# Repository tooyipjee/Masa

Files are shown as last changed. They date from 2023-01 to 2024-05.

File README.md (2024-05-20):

**Masa: A Smart, Energy-Efficient Retro Clock**
=====================================================
**Introduction**
---------------
Masa, the Malaysian word for time, is a project that brings together modern electronic components to achieve a beautiful vintage look. Masa combines the aesthetic of traditional Nixie tubes with modern LED technology and advanced features.

**Project Overview**
--------------------
Masa is a type of electronic clock that replicates the vintage aesthetic of traditional Nixie clocks while using modern LED technology. It displays the time and can also display additional panels such as weather, tickers, and other illustrations. Masa has internet connectivity, allowing it to retrieve data from the internet and features several onboard environmental sensors.

**Key Features**
----------------
* LEDs with full brightness and color control
* Environmental sensor to measure room temperature and humidity
* Phototransistor for ambient light measurement
* ESP32-S2 to drive and interface with sensors and get the latest time from the NTP server over WiFi
* Compatible with rapidly prototype-able Cricut-based perspex "displays"
* Powered by USB-C

**Specification**
---------------
* Microcontroller: ESP32-S2
* WiFi: 802.11b/g/n
* FLASH: 4MB
* Programming: USB over UART
* Humidity and Temperature Sensor: SHT20
    + Capacitive type humidity sensor
    + Band gap temperature sensor
    + Digital processing unit - I2C
* Light Sensor: TEMT6000X01
    + High photo sensitivity
    + Adapted to human eye responsivity
    + Angle of half sensitivity ± 60°
* Power: USB-C + 3.3V LDO

**Acknowledgement**
----------------
Special thanks to JLCPCB for sponsoring this project. Their rapid prototyping and high-quality assembly services enabled us to bring this project to life.

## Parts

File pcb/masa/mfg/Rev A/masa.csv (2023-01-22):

Comment | Designator | Footprint | LCSC
ANT3216LL00R2400A | AE1 | Resistor_SMD:R_1206_3216Metric_Pad1.30x1.75mm_HandSolder | C293767
10u | C3,C44,C45,C117,C121,C122 | Capacitor_SMD:C_0805_2012Metric | C15850
100uF_E | C118,C119,C120 | Capacitor_SMD:CP_Elec_6.3x7.7 | C127971
100p | C14 | Capacitor_SMD:C_0402_1005Metric | C1546
100n | C1,C2,C10,C13,C15,C16,C17,C18,C21,C22,C23,C24,C25,C26,C27,C28,C29,C30,C31,C32,C33,C34,C35,C36,C37,C38,C39,C40,C41,C42,C43,C46,C47,C48,C49,C50,C51,C52,C53,C54,C55,C56,C57,C58,C59,C60,C61,C62,C63,C64,C65,C66,C67,C68,C69,C70,C71,C72,C73,C74,C75,C76,C77,C78,C79,C80,C81,C82,C83,C84,C85,C86,C87,C88,C89,C90,C91,C92,C93,C94,C95,C96,C97,C98,C99,C100,C101,C102,C103,C104,C105,C106,C107,C108,C109,C110,C111,C112,C113,C114,C115,C116,C124,C125 | Capacitor_SMD:C_0402_1005Metric | C307331
1u | C4,C12,C19,C20 | Capacitor_SMD:C_0402_1005Metric | C52923
20p | C5,C9 | Capacitor_SMD:C_0402_1005Metric | C1554
4p | C6 | Capacitor_SMD:C_0402_1005Metric | C311704
10u_0402 | C7,C11 | Capacitor_SMD:C_0402_1005Metric | C315248
5p | C8 | Capacitor_SMD:C_0402_1005Metric | C1573
Green_0603 | D1,D2,D3 | LED_SMD:LED_0603_1608Metric | C72043
MountingHole | H1,H2,H3,H4,H5,H6,H7,H8,H9,H10,H11,H12,H13,H14,H15,H16,H17,H18,H19,H20,H21,H22,H23,H24 | MountingHole:MountingHole_2.7mm_M2.5
ESP32-S2FH4 | IC1 | QFN40P700X700X90-57N-D | C2840995
AMS1117-3.3 | IC2 | Package_TO_SOT_SMD:SOT-223-3_TabPin2 | C6186
W25Q64JVSSIQ | IC3 | SOIC127P790X216-8N | C83140
SHT20 | IC4 | SON100P300X300X110-7N
TXS0108EPWR | IC5 | SOP65P640X120-20N | C17206
U.FL-R-SMT-1_10_ | J1 | SamacSys_Parts:U.FL-R-SMT-1_10_ | C88373
GT-USB-7010 | J2 | Connectors_JT:GT-USB-7010A | C963370
TC2050-IDC | J3 | TC2050-IDC
KF350-3.5-2P | J4 | KF350352P | C474892
1.8nH | L1,L2 | Inductor_SMD:L_0402_1005Metric
WS2812B-2020 | LED1,LED2,LED3,LED4,LED5,LED6,LED7,LED8,LED9,LED10,LED11,LED12,LED13,LED14,LED15,LED16,LED17,LED18,LED19,LED20,LED21,LED22,LED23,LED24,LED25,LED26,LED27,LED28,LED29,LED30,LED31,LED32,LED33,LED34,LED35,LED36,LED37,LED38,LED39,LED40,LED41,LED42,LED43,LED44,LED45,LED46,LED47,LED48,LED49,LED50,LED51,LED52,LED53,LED54,LED55,LED56,LED57,LED58,LED59,LED60,LED61,LED62,LED63,LED64,LED65,LED66,LED67,LED68,LED69,LED70,LED71,LED72,LED73,LED74,LED75,LED76,LED77,LED78,LED79,LED80,LED81,LED82,LED83,LED84,LED85,LED86,LED87,LED88,LED89,LED90,LED91,LED92,LED93 | WS2812B2020 | C965555
MUN5214DW1T1G | Q1 | Package_TO_SOT_SMD:SOT-363_SC-70-6 | C94403
TEMT6000X01 | Q2 | TEMT6000X01 | C94098
DNF_0402 | R1 | Resistor_SMD:R_0402_1005Metric
4.7k | R11,R12 | Resistor_SMD:R_0402_1005Metric | C25900
2.2k | R16 | Resistor_SMD:R_0402_1005Metric | C25879
1k | R2,R3 | Resistor_SMD:R_0402_1005Metric | C11702
DNF_0805 | R4,R9,R13 | Resistor_SMD:R_0805_2012Metric_Pad1.20x1.40mm_HandSolder
0 | R5,R14,R15 | Resistor_SMD:R_0805_2012Metric_Pad1.20x1.40mm_HandSolder | C17477
10k | R6,R7,R8,R10,R17 | Resistor_SMD:R_0402_1005Metric | C25744
TS-1101-C-W | S1,S2 | TS1101CW | C318938
K3-1296S-E1 | S3 | K31296SE1 | C128955
TestPoint | TP1,TP2,TP3,TP5,TP9,TP10,TP11,TP12 | TestPoint:TestPoint_THTPad_D1.0mm_Drill0.5mm
TestPoint | TP4,TP6,TP7,TP8 | TestPoint:TestPoint_THTPad_1.0x1.0mm_Drill0.5mm
CH340C | U1 | Package_SO:SOIC-16_3.9x9.9mm_P1.27mm | C84681
SX25Y040000BF1T-C | Y1 | Crystal:Crystal_SMD_2520-4Pin_2.5x2.0mm | C271649

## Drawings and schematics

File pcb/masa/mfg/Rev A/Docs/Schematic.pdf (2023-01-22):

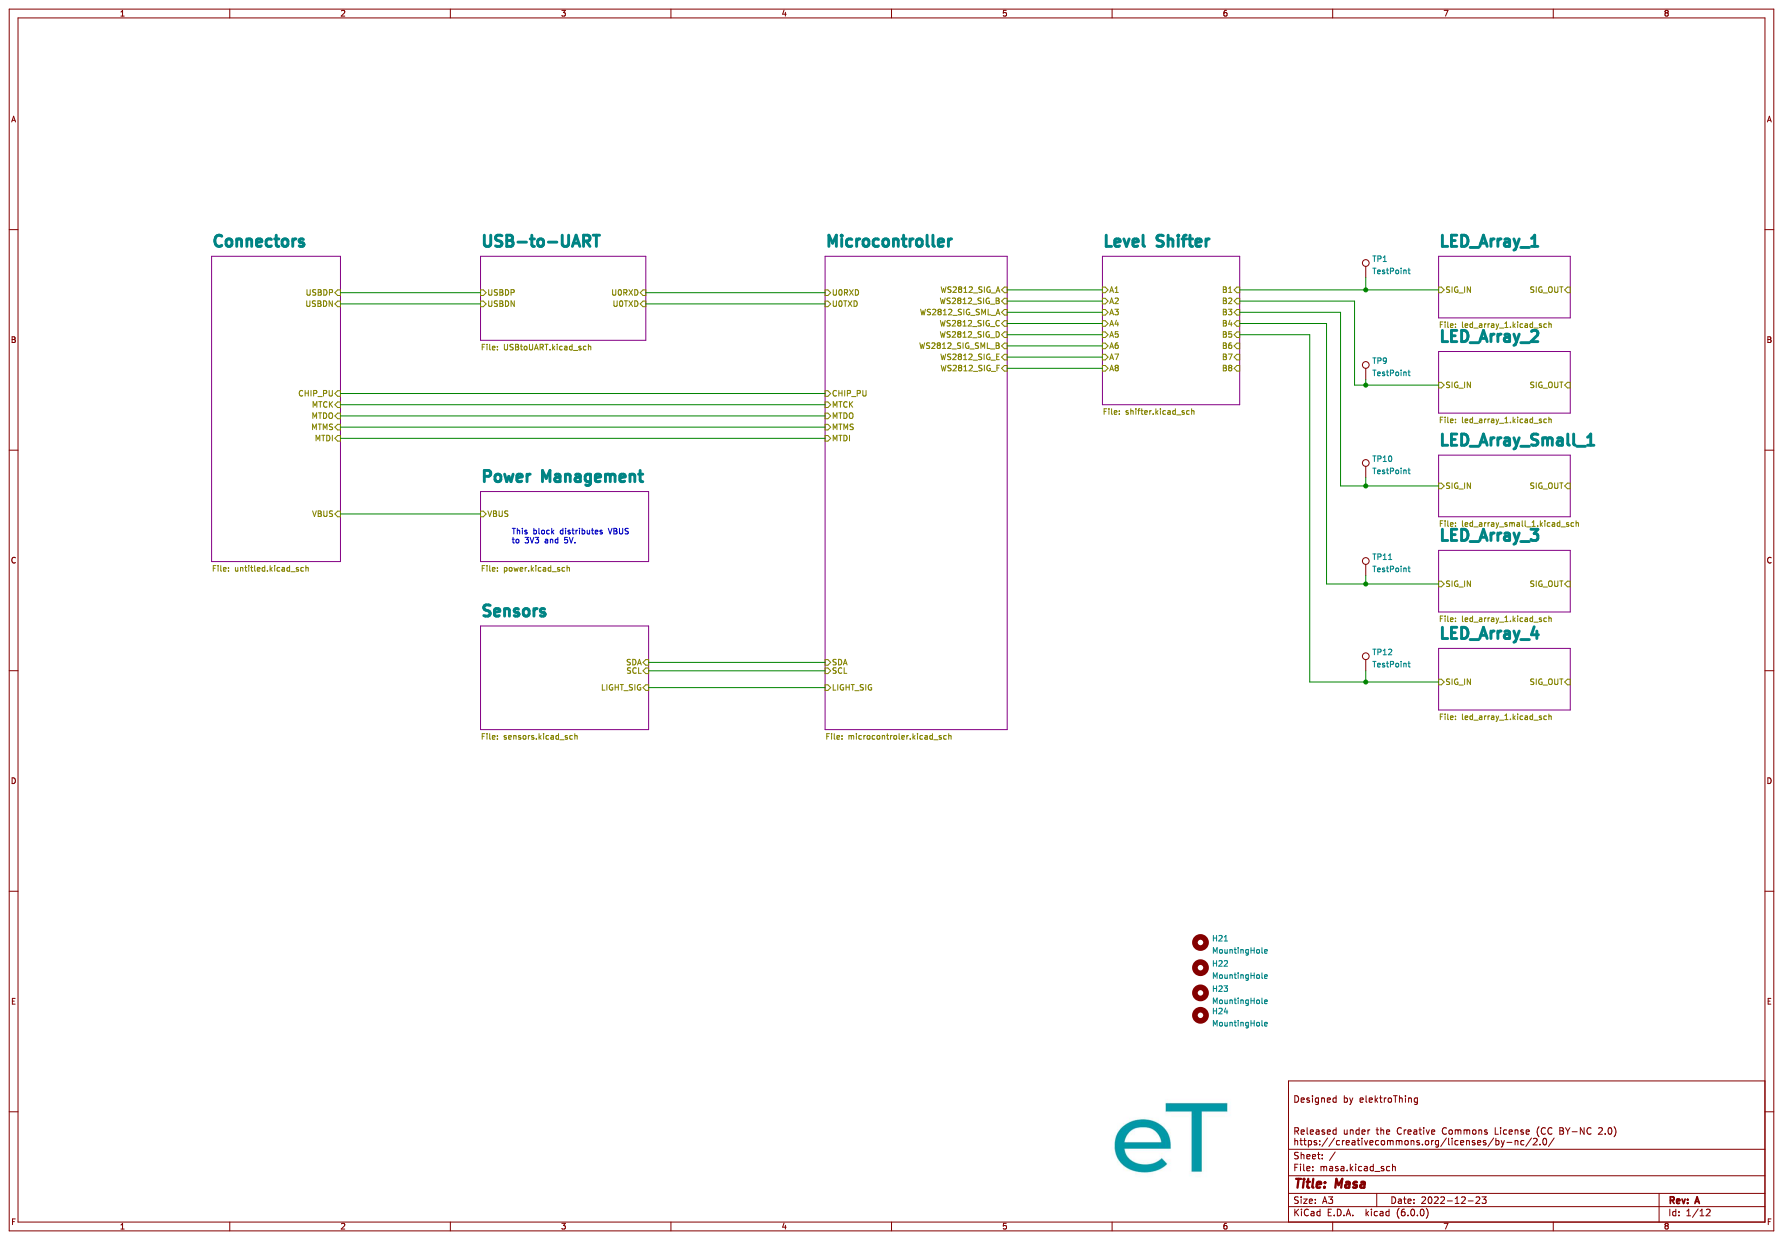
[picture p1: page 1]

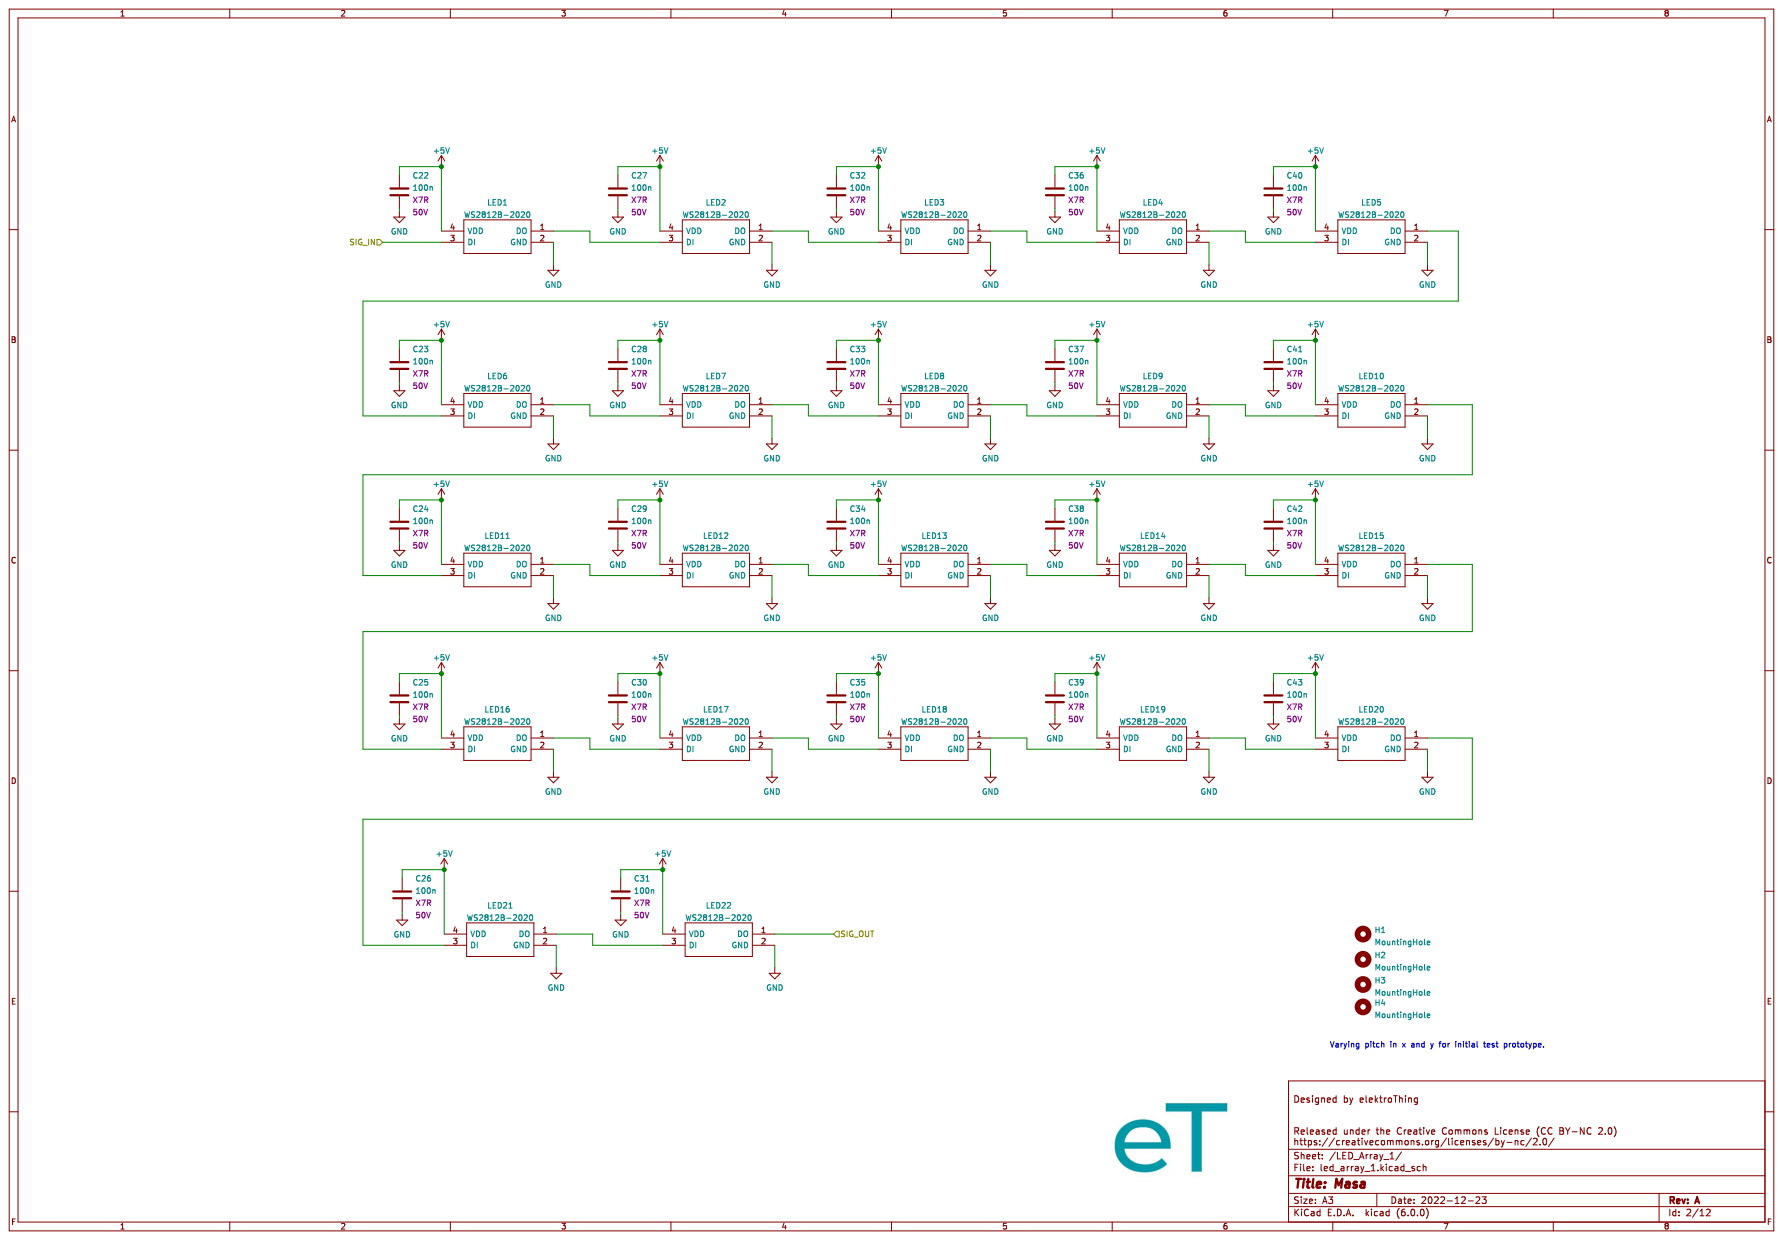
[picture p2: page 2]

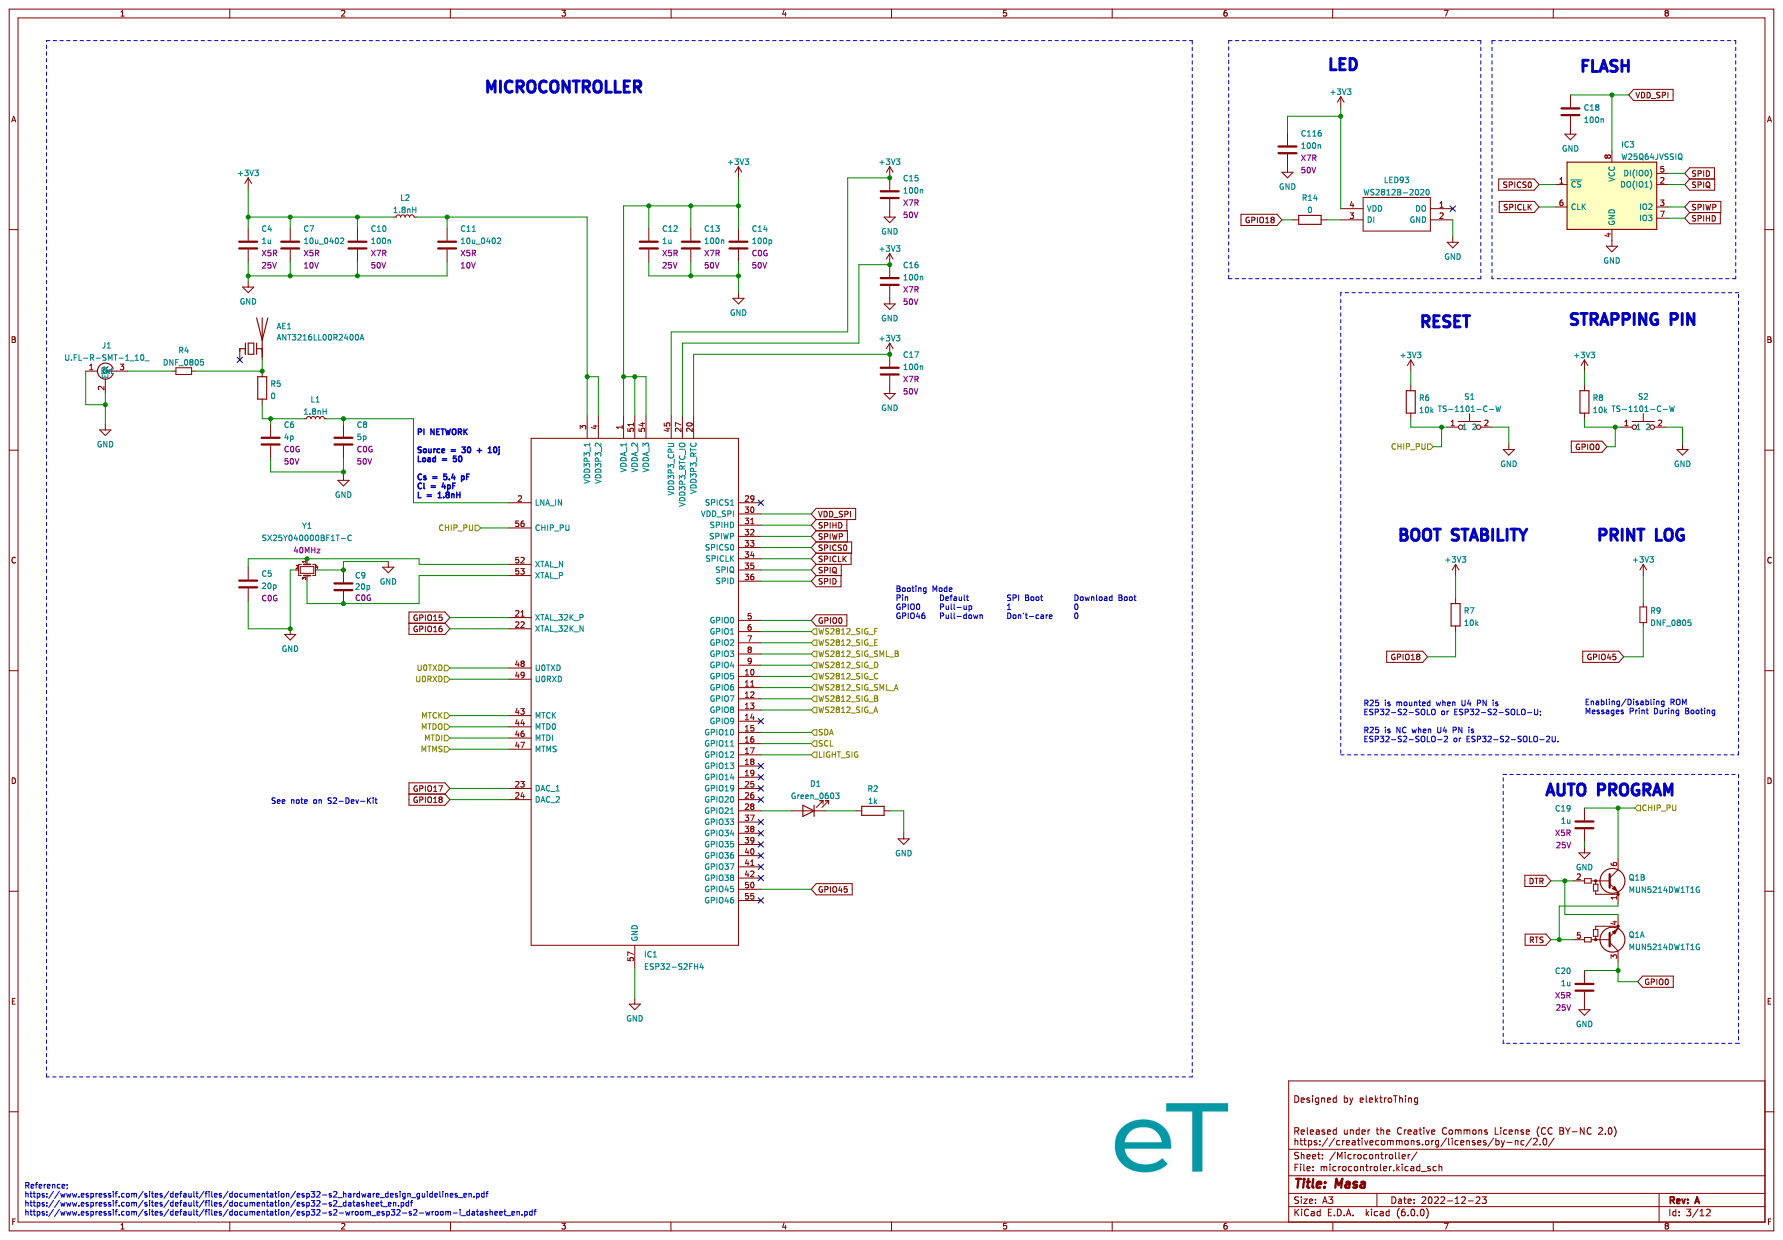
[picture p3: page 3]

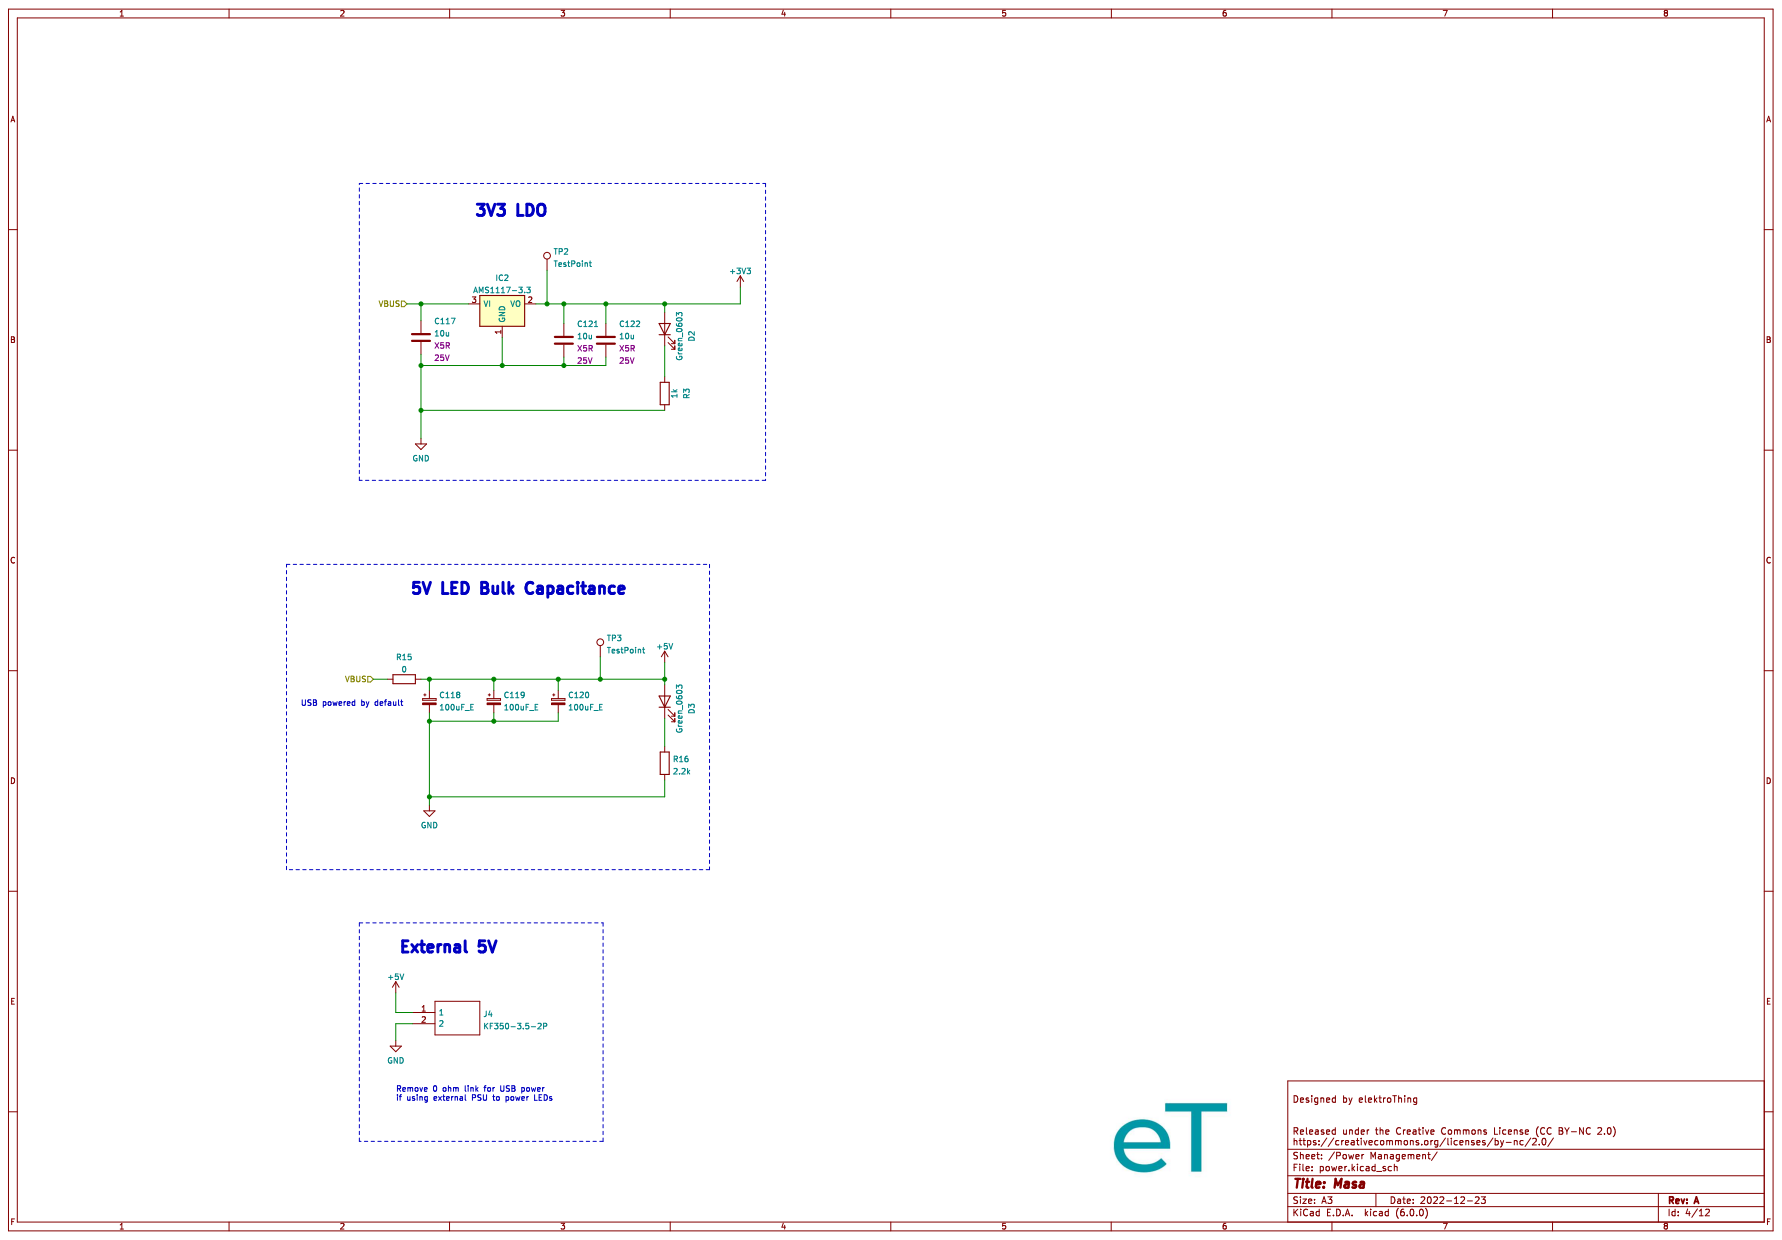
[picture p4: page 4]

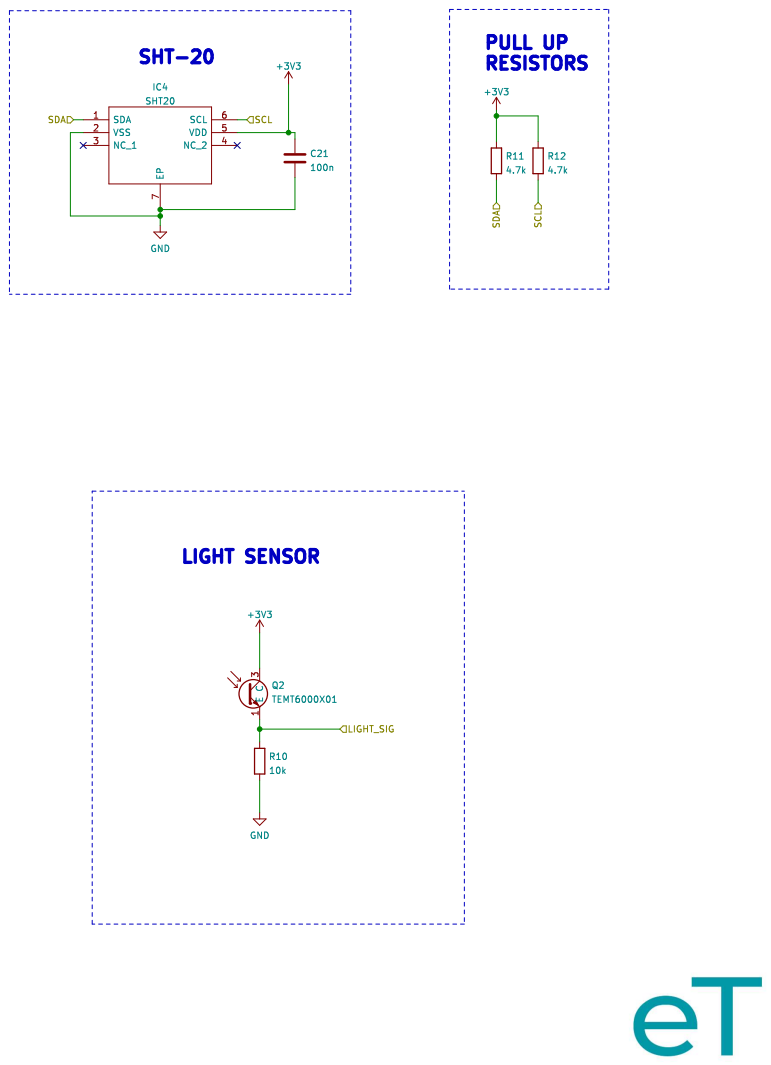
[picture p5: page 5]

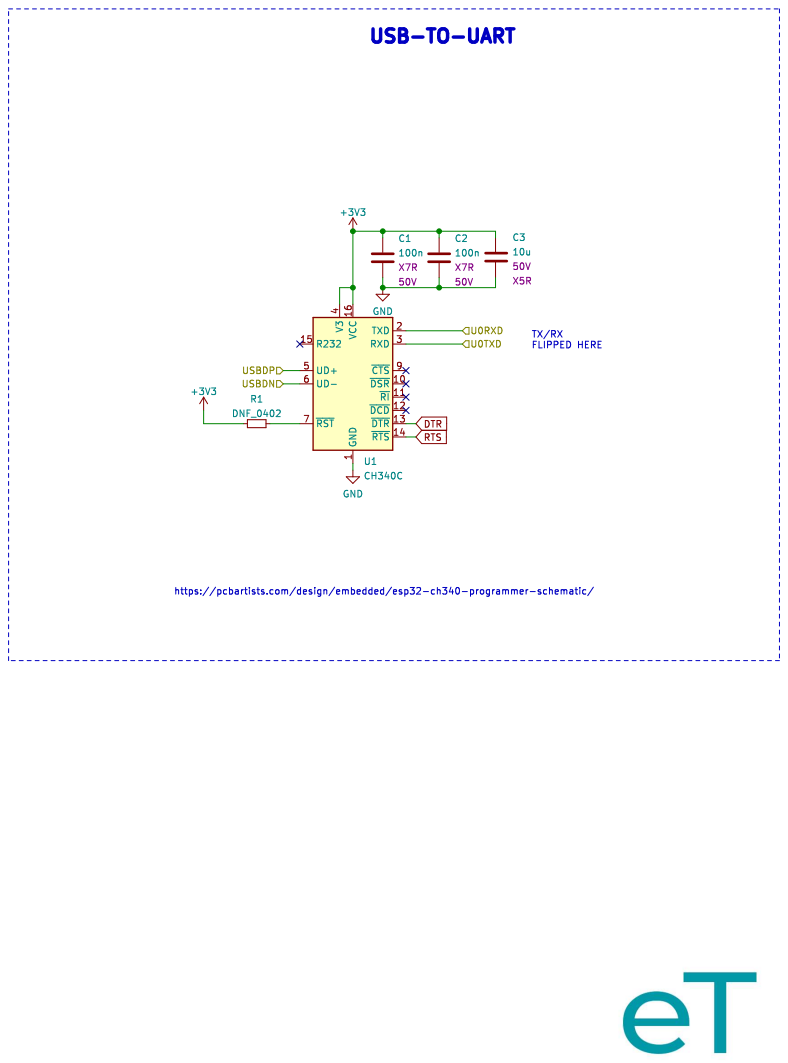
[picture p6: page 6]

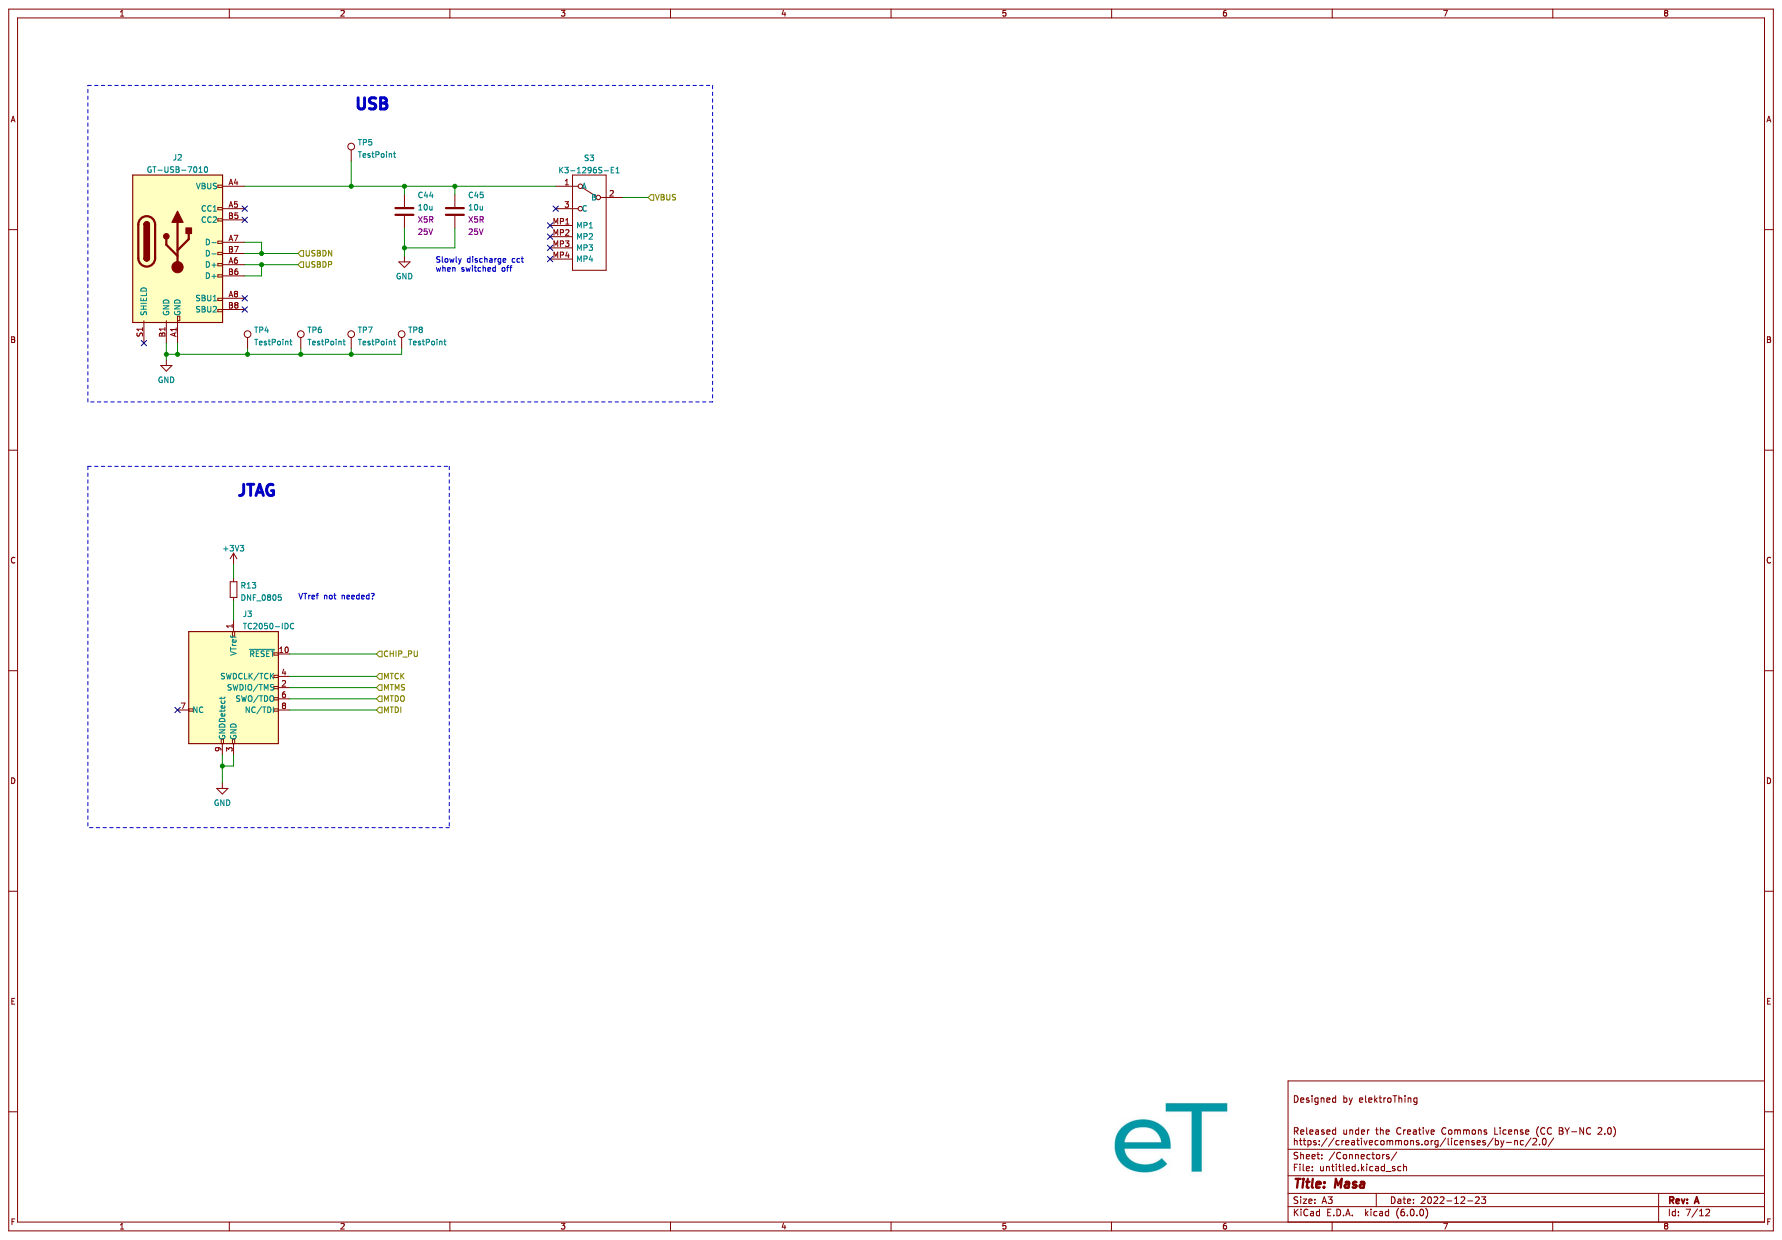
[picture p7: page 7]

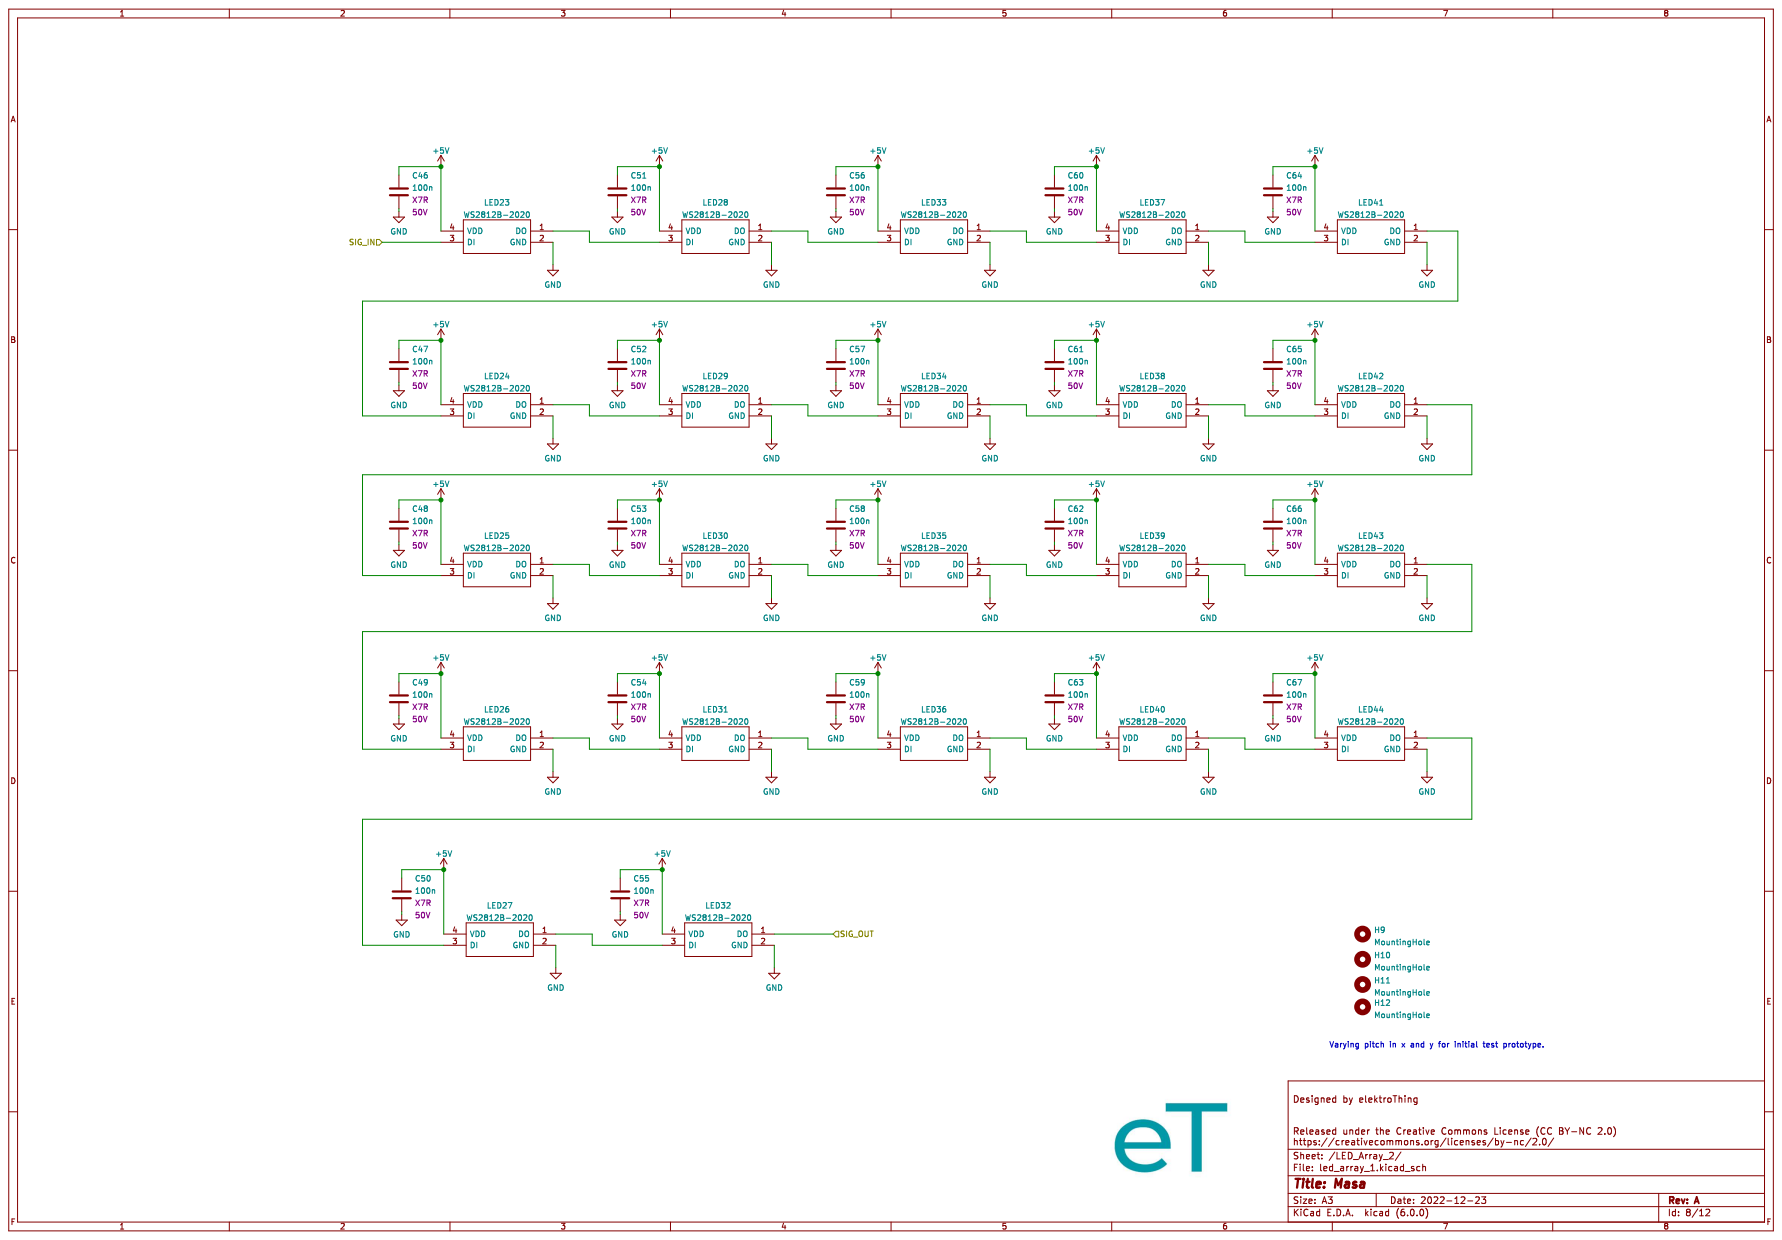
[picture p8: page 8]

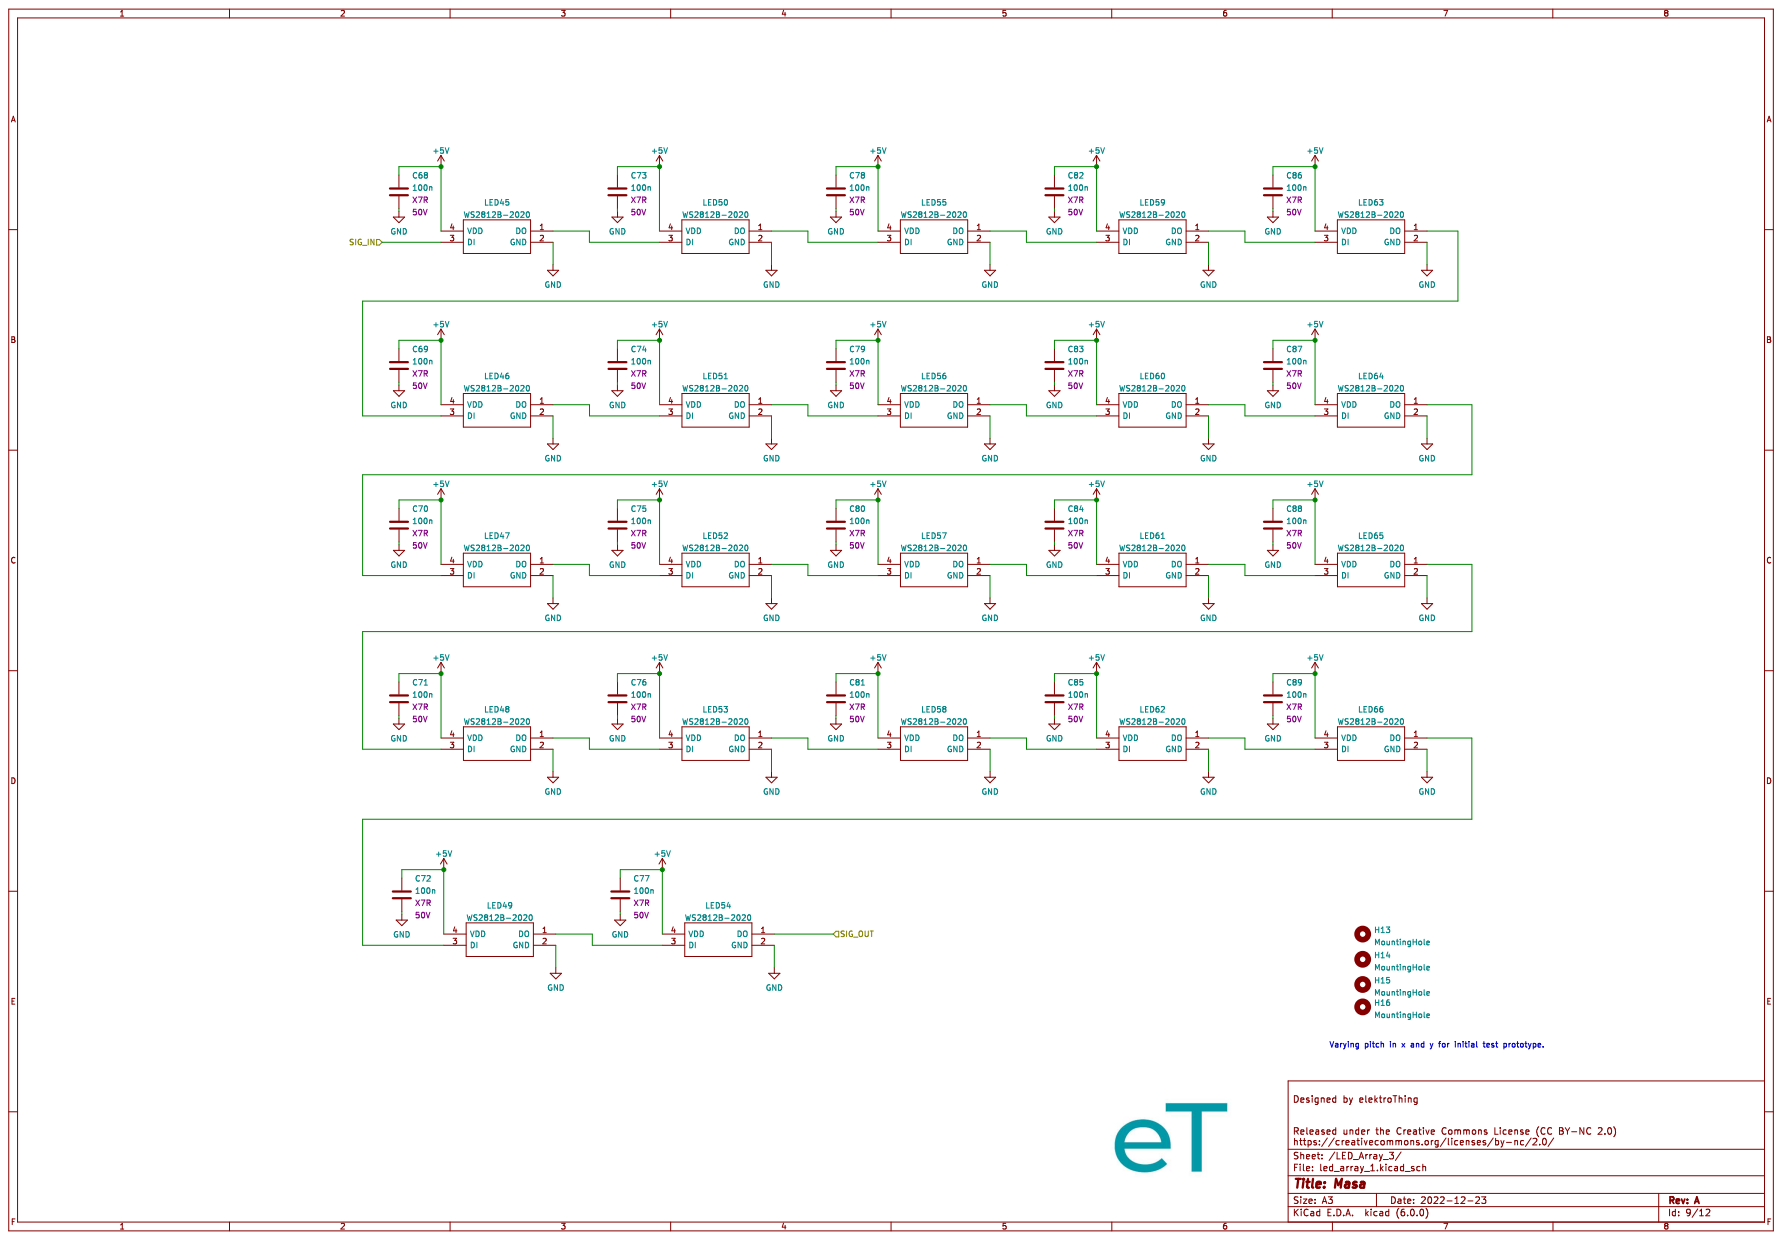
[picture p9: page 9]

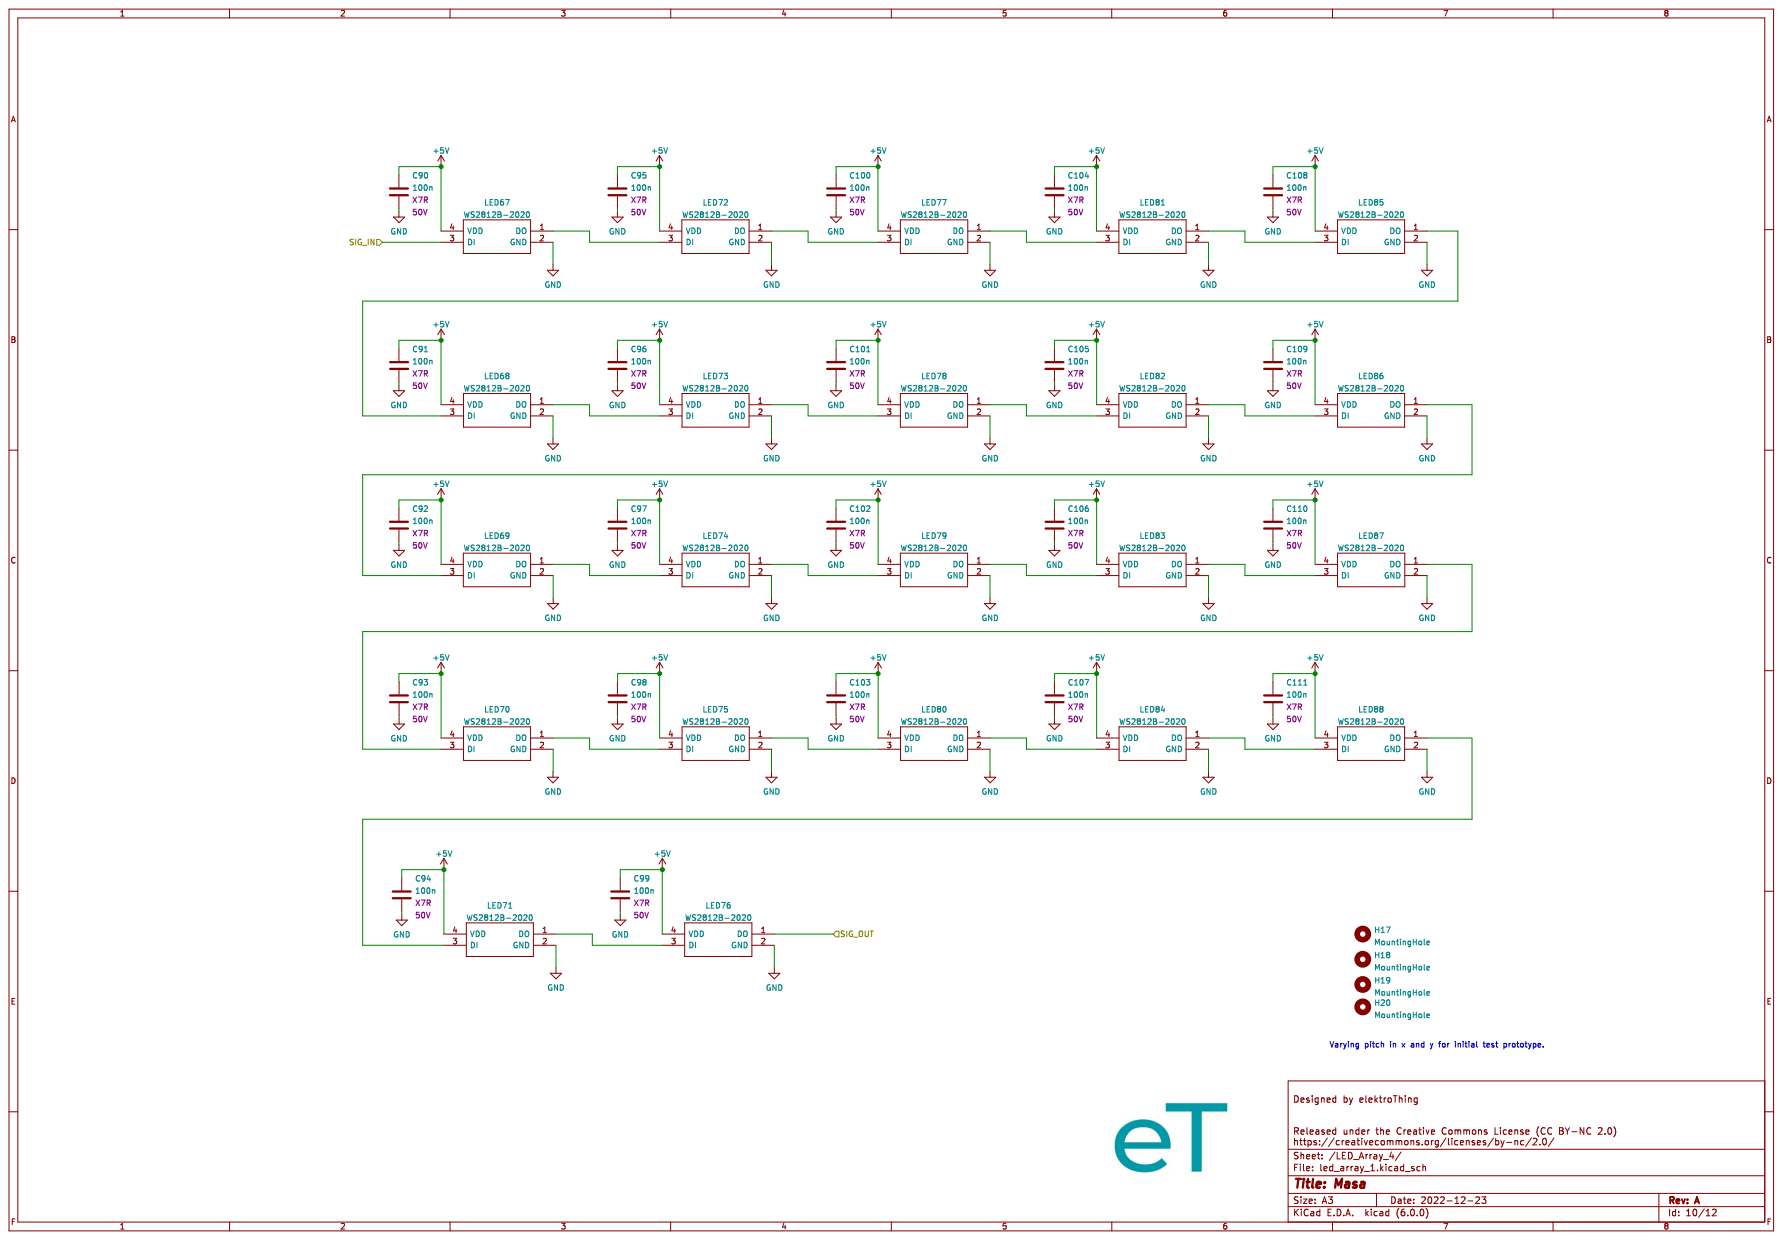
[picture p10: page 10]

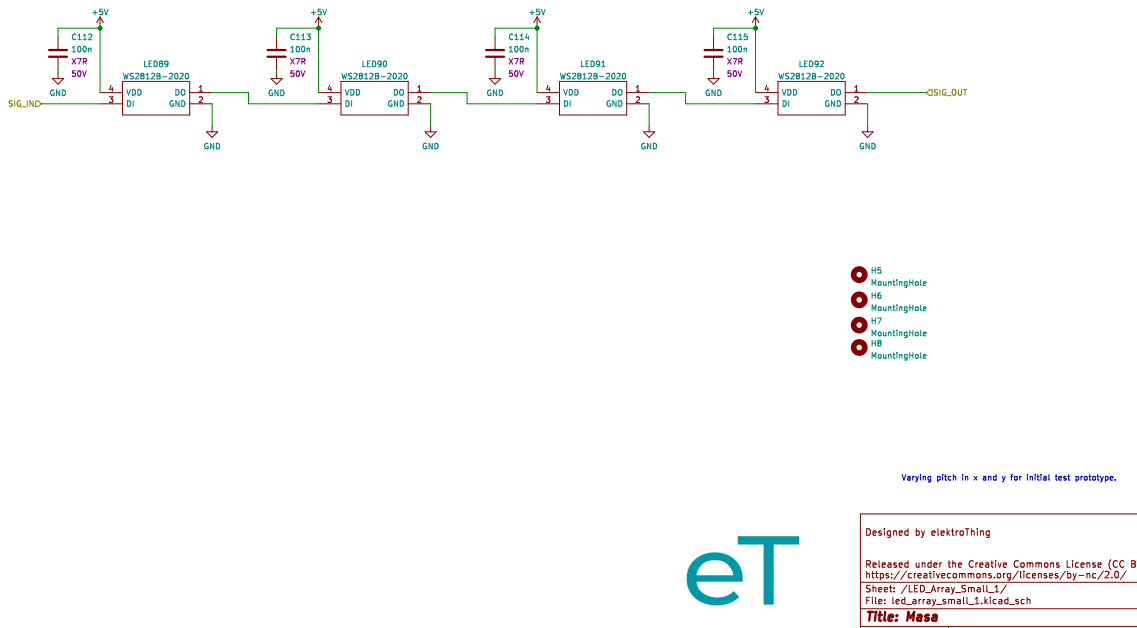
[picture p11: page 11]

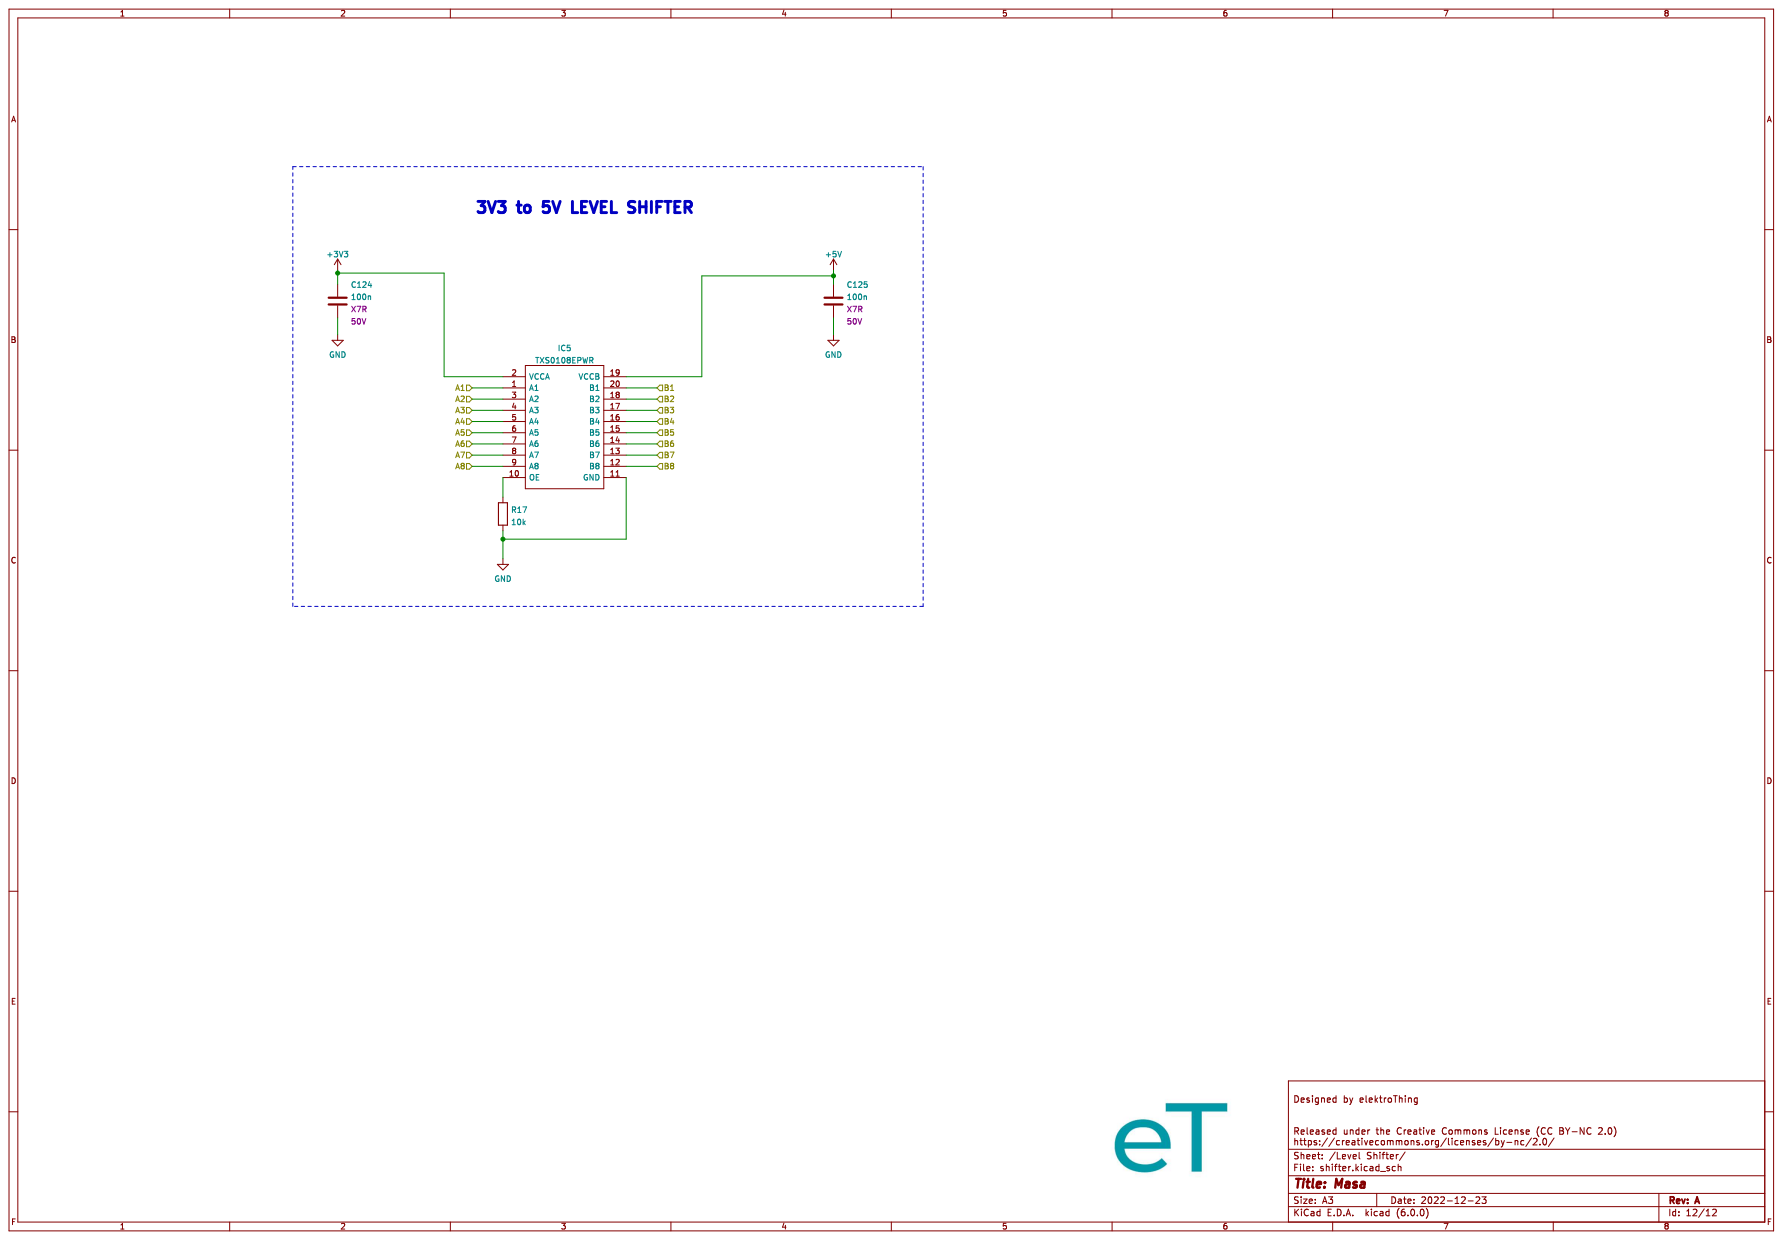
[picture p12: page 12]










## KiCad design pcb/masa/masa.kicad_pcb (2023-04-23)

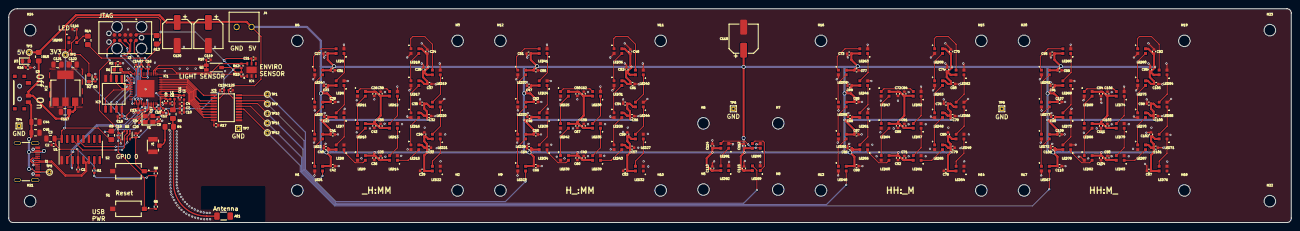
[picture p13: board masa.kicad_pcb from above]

Board: 4 copper layers, 300.0 x 50.0 mm, 292 parts (0 on the bottom side), 144 nets.

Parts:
AE1: ANT3216LL00R2400A; R_1206_3216Metric_Pad1.30x1.75mm_HandSolder
C1, C2, C10, C13, C15, C16, C17, C18, C21, C22, C23, C24, C25, C26, C27, C28, C29, C30, C31, C32, C33, C34, C35, C36, C37, C38, C39, C40, C41, C42, C43, C46, C47, C48, C49, C50, C51, C52, C53, C54, C55, C56, C57, C58, C59, C60, C61, C62, C63, C64, C65, C66, C67, C68, C69, C70, C71, C72, C73, C74, C75, C76, C77, C78, C79, C80, C81, C82, C83, C84, C85, C86, C87, C88, C89, C90, C91, C92, C93, C94, C95, C96, C97, C98, C99, C100, C101, C102, C103, C104, C105, C106, C107, C108, C109, C110, C111, C112, C113, C114, C115, C116, C124, C125: 100n; C_0402_1005Metric
C3, C44, C45, C117, C121, C122: 10u; C_0805_2012Metric
C4, C12, C19, C20: 1u; C_0402_1005Metric
C5, C9: 20p; C_0402_1005Metric
C6: 4p; C_0402_1005Metric
C7, C11: 10u_0402; C_0402_1005Metric
C8: 5p; C_0402_1005Metric
C14: 100p; C_0402_1005Metric
C118, C119, C120: 100uF_E; CP_Elec_6.3x7.7
D1, D2, D3: Green_0603; LED_0603_1608Metric
H1, H2, H3, H4, H5, H6, H7, H8, H9, H10, H11, H12, H13, H14, H15, H16, H17, H18, H19, H20, H21, H22, H23, H24: MountingHole; MountingHole_2.7mm_M2.5
IC1: ESP32-S2FH4; QFN40P700X700X90-57N-D
IC2: AMS1117-3.3; SOT-223-3_TabPin2
IC3: W25Q64JVSSIQ; SOIC127P790X216-8N
IC4: SHT20; SON100P300X300X110-7N
IC5: TXS0108EPWR; SOP65P640X120-20N
J1: U.FL-R-SMT-1_10_
J2: GT-USB-7010; GT-USB-7010A
J3: TC2050-IDC
J4: KF350-3.5-2P; KF350352P
L1, L2: 1.8nH; L_0402_1005Metric
LED1, LED2, LED3, LED4, LED5, LED6, LED7, LED8, LED9, LED10, LED11, LED12, LED13, LED14, LED15, LED16, LED17, LED18, LED19, LED20, LED21, LED22, LED23, LED24, LED25, LED26, LED27, LED28, LED29, LED30, LED31, LED32, LED33, LED34, LED35, LED36, LED37, LED38, LED39, LED40, LED41, LED42, LED43, LED44, LED45, LED46, LED47, LED48, LED49, LED50, LED51, LED52, LED53, LED54, LED55, LED56, LED57, LED58, LED59, LED60, LED61, LED62, LED63, LED64, LED65, LED66, LED67, LED68, LED69, LED70, LED71, LED72, LED73, LED74, LED75, LED76, LED77, LED78, LED79, LED80, LED81, LED82, LED83, LED84, LED85, LED86, LED87, LED88, LED89, LED90, LED91, LED92, LED93: WS2812B-2020; WS2812B2020
Q1: MUN5214DW1T1G; SOT-363_SC-70-6
Q2: TEMT6000X01
R1: DNF_0402; R_0402_1005Metric
R2, R3: 1k; R_0402_1005Metric
R4, R9, R13: DNF_0805; R_0805_2012Metric_Pad1.20x1.40mm_HandSolder
R5, R14, R15: 0; R_0805_2012Metric_Pad1.20x1.40mm_HandSolder
R6, R7, R8, R10, R17: 10k; R_0402_1005Metric
R11, R12: 4.7k; R_0402_1005Metric
R16: 2.2k; R_0402_1005Metric
S1, S2: TS-1101-C-W; TS1101CW
S3: K3-1296S-E1; K31296SE1
TP1, TP2, TP3, TP5, TP9, TP10, TP11, TP12: TestPoint; TestPoint_THTPad_D1.0mm_Drill0.5mm
TP4, TP6, TP7, TP8: TestPoint; TestPoint_THTPad_1.0x1.0mm_Drill0.5mm
U1: CH340C; SOIC-16_3.9x9.9mm_P1.27mm
Y1: SX25Y040000BF1T-C; Crystal_SMD_2520-4Pin_2.5x2.0mm

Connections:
+3V3: C1.1, C2.1, C3.1, C4.1, C7.1, C10.1, C12.1, C13.1, C14.1, C15.1, C16.1, C17.1, C21.1, C116.1, C121.1, C122.1, C124.1, D2.2 (A), IC1.1 (VDDA_1), IC1.20 (VDD3P3_RTC), IC1.27 (VDD3P3_RTC_IO), IC1.45 (VDD3P3_CPU), IC1.51 (VDDA_2), IC1.54 (VDDA_3), IC2.2 (VO), IC4.5 (VDD), IC5.2 (VCCA), L2.1, LED93.4 (VDD), Q2.3 (C), R1.2, R6.1, R7.1, R8.1, R9.1, R11.1, R12.1, R13.2, TP2.1, U1.4 (V3), U1.16 (VCC)
+5V: C22.1, C23.1, C24.1, C25.1, C26.1, C27.1, C28.1, C29.1, C30.1, C31.1, C32.1, C33.1, C34.1, C35.1, C36.1, C37.1, C38.1, C39.1, C40.1, C41.1, C42.1, C43.1, C46.1, C47.1, C48.1, C49.1, C50.1, C51.1, C52.1, C53.1, C54.1, C55.1, C56.1, C57.1, C58.1, C59.1, C60.1, C61.1, C62.1, C63.1, C64.1, C65.1, C66.1, C67.1, C68.1, C69.1, C70.1, C71.1, C72.1, C73.1, C74.1, C75.1, C76.1, C77.1, C78.1, C79.1, C80.1, C81.1, C82.1, C83.1, C84.1, C85.1, C86.1, C87.1, C88.1, C89.1, C90.1, C91.1, C92.1, C93.1, C94.1, C95.1, C96.1, C97.1, C98.1, C99.1, C100.1, C101.1, C102.1, C103.1, C104.1, C105.1, C106.1, C107.1, C108.1, C109.1, C110.1, C111.1, C112.1, C113.1, C114.1, C115.1, C118.1, C119.1, C120.1, C125.1, D3.2 (A), IC5.19 (VCCB), J4.1, LED1.4 (VDD), LED2.4 (VDD), LED3.4 (VDD), LED4.4 (VDD), LED5.4 (VDD), LED6.4 (VDD), LED7.4 (VDD), LED8.4 (VDD), LED9.4 (VDD), LED10.4 (VDD), LED11.4 (VDD), LED12.4 (VDD), LED13.4 (VDD), LED14.4 (VDD), LED15.4 (VDD), LED16.4 (VDD), LED17.4 (VDD), LED18.4 (VDD), LED19.4 (VDD), LED20.4 (VDD), LED21.4 (VDD), LED22.4 (VDD), LED23.4 (VDD), LED24.4 (VDD), LED25.4 (VDD), LED26.4 (VDD), LED27.4 (VDD), LED28.4 (VDD), LED29.4 (VDD), LED30.4 (VDD), LED31.4 (VDD), LED32.4 (VDD), LED33.4 (VDD), LED34.4 (VDD), LED35.4 (VDD), LED36.4 (VDD), LED37.4 (VDD), LED38.4 (VDD), LED39.4 (VDD), LED40.4 (VDD), LED41.4 (VDD), LED42.4 (VDD), LED43.4 (VDD), LED44.4 (VDD), LED45.4 (VDD), LED46.4 (VDD), LED47.4 (VDD), LED48.4 (VDD), LED49.4 (VDD), LED50.4 (VDD), LED51.4 (VDD), LED52.4 (VDD), LED53.4 (VDD), LED54.4 (VDD), LED55.4 (VDD), LED56.4 (VDD), LED57.4 (VDD), LED58.4 (VDD), LED59.4 (VDD), LED60.4 (VDD), LED61.4 (VDD), LED62.4 (VDD), LED63.4 (VDD), LED64.4 (VDD), LED65.4 (VDD), LED66.4 (VDD), LED67.4 (VDD), LED68.4 (VDD), LED69.4 (VDD), LED70.4 (VDD), LED71.4 (VDD), LED72.4 (VDD), LED73.4 (VDD), LED74.4 (VDD), LED75.4 (VDD), LED76.4 (VDD), LED77.4 (VDD), LED78.4 (VDD), LED79.4 (VDD), LED80.4 (VDD), LED81.4 (VDD), LED82.4 (VDD), LED83.4 (VDD), LED84.4 (VDD), LED85.4 (VDD), LED86.4 (VDD), LED87.4 (VDD), LED88.4 (VDD), LED89.4 (VDD), LED90.4 (VDD), LED91.4 (VDD), LED92.4 (VDD), R15.2, TP3.1
/Connectors/CHIP_PU: C19.1, IC1.56 (CHIP_PU), J3.10 (~RESET), Q1.6 (C2), R6.2, S1.1
/Connectors/MTCK: IC1.43 (MTCK), J3.4 (SWDCLK/TCK)
/Connectors/MTDI: IC1.46 (MTDI), J3.8 (NC/TDI)
/Connectors/MTDO: IC1.44 (MTD0), J3.6 (SWO/TDO)
/Connectors/MTMS: IC1.47 (MTMS), J3.2 (SWDIO/TMS)
/Connectors/USBDN: J2.A7 (D-), J2.B7 (D-), U1.6 (UD-)
/Connectors/USBDP: J2.A6 (D+), J2.B6 (D+), U1.5 (UD+)
/Connectors/VBUS: C117.1, IC2.3 (VI), R15.1, S3.2 (B)
/LED_Array_1/SIG_IN: IC5.20 (B1), LED1.3 (DI), TP1.1
/LED_Array_2/SIG_IN: IC5.18 (B2), LED23.3 (DI), TP9.1
/LED_Array_3/SIG_IN: IC5.16 (B4), LED45.3 (DI), TP11.1
/LED_Array_4/SIG_IN: IC5.15 (B5), LED67.3 (DI), TP12.1
/LED_Array_Small_1/SIG_IN: IC5.17 (B3), LED89.3 (DI), TP10.1
/Level Shifter/A1: IC1.13 (GPIO8), IC5.1 (A1)
/Level Shifter/A2: IC1.12 (GPIO7), IC5.3 (A2)
/Level Shifter/A3: IC1.11 (GPIO6), IC5.4 (A3)
/Level Shifter/A4: IC1.10 (GPIO5), IC5.5 (A4)
/Level Shifter/A5: IC1.9 (GPIO4), IC5.6 (A5)
/Level Shifter/A6: IC1.8 (GPIO3), IC5.7 (A6)
/Level Shifter/A7: IC1.7 (GPIO2), IC5.8 (A7)
/Level Shifter/A8: IC1.6 (GPIO1), IC5.9 (A8)
/Microcontroller/LIGHT_SIG: IC1.17 (GPIO12), Q2.1 (E), Q2.2 (E), R10.1
/Microcontroller/SCL: IC1.16 (GPIO11), IC4.6 (SCL), R12.2
/Microcontroller/SDA: IC1.15 (GPIO10), IC4.1 (SDA), R11.2
/Microcontroller/U0RXD: IC1.49 (U0RXD), U1.2 (TXD)
/Microcontroller/U0TXD: IC1.48 (U0TXD), U1.3 (RXD)
DTR: Q1.2 (B2), Q1.4 (E1), U1.13 (~DTR)
GND: C1.2, C2.2, C3.2, C4.2, C5.2, C6.2, C7.2, C8.2, C9.1, C10.2, C11.2, C12.2, C13.2, C14.2, C15.2, C16.2, C17.2, C18.2, C19.2, C20.2, C21.2, C22.2, C23.2, C24.2, C25.2, C26.2, C27.2, C28.2, C29.2, C30.2, C31.2, C32.2, C33.2, C34.2, C35.2, C36.2, C37.2, C38.2, C39.2, C40.2, C41.2, C42.2, C43.2, C44.2, C45.2, C46.2, C47.2, C48.2, C49.2, C50.2, C51.2, C52.2, C53.2, C54.2, C55.2, C56.2, C57.2, C58.2, C59.2, C60.2, C61.2, C62.2, C63.2, C64.2, C65.2, C66.2, C67.2, C68.2, C69.2, C70.2, C71.2, C72.2, C73.2, C74.2, C75.2, C76.2, C77.2, C78.2, C79.2, C80.2, C81.2, C82.2, C83.2, C84.2, C85.2, C86.2, C87.2, C88.2, C89.2, C90.2, C91.2, C92.2, C93.2, C94.2, C95.2, C96.2, C97.2, C98.2, C99.2, C100.2, C101.2, C102.2, C103.2, C104.2, C105.2, C106.2, C107.2, C108.2, C109.2, C110.2, C111.2, C112.2, C113.2, C114.2, C115.2, C116.2, C117.2, C118.2, C119.2, C120.2, C121.2, C122.2, C124.2, C125.2, IC1.57 (GND), IC2.1 (GND), IC3.4 (GND), IC4.2 (VSS), IC4.7 (EP), IC5.11 (GND), J1.1 (Ext), J1.2 (Ext), J2.A1 (GND), J2.B1 (GND), J3.3 (GND), J3.5 (GND), J3.9 (GNDDetect), J4.2, LED1.2 (GND), LED2.2 (GND), LED3.2 (GND), LED4.2 (GND), LED5.2 (GND), LED6.2 (GND), LED7.2 (GND), LED8.2 (GND), LED9.2 (GND), LED10.2 (GND), LED11.2 (GND), LED12.2 (GND), LED13.2 (GND), LED14.2 (GND), LED15.2 (GND), LED16.2 (GND), LED17.2 (GND), LED18.2 (GND), LED19.2 (GND), LED20.2 (GND), LED21.2 (GND), LED22.2 (GND), LED23.2 (GND), LED24.2 (GND), LED25.2 (GND), LED26.2 (GND), LED27.2 (GND), LED28.2 (GND), LED29.2 (GND), LED30.2 (GND), LED31.2 (GND), LED32.2 (GND), LED33.2 (GND), LED34.2 (GND), LED35.2 (GND), LED36.2 (GND), LED37.2 (GND), LED38.2 (GND), LED39.2 (GND), LED40.2 (GND), LED41.2 (GND), LED42.2 (GND), LED43.2 (GND), LED44.2 (GND), LED45.2 (GND), LED46.2 (GND), LED47.2 (GND), LED48.2 (GND), LED49.2 (GND), LED50.2 (GND), LED51.2 (GND), LED52.2 (GND), LED53.2 (GND), LED54.2 (GND), LED55.2 (GND), LED56.2 (GND), LED57.2 (GND), LED58.2 (GND), LED59.2 (GND), LED60.2 (GND), LED61.2 (GND), LED62.2 (GND), LED63.2 (GND), LED64.2 (GND), LED65.2 (GND), LED66.2 (GND), LED67.2 (GND), LED68.2 (GND), LED69.2 (GND), LED70.2 (GND), LED71.2 (GND), LED72.2 (GND), LED73.2 (GND), LED74.2 (GND), LED75.2 (GND), LED76.2 (GND), LED77.2 (GND), LED78.2 (GND), LED79.2 (GND), LED80.2 (GND), LED81.2 (GND), LED82.2 (GND), LED83.2 (GND), LED84.2 (GND), LED85.2 (GND), LED86.2 (GND), LED87.2 (GND), LED88.2 (GND), LED89.2 (GND), LED90.2 (GND), LED91.2 (GND), LED92.2 (GND), LED93.2 (GND), R2.2, R3.2, R10.2, R16.2, R17.1, S1.2, S2.2, TP4.1, TP6.1, TP7.1, TP8.1, U1.1 (GND), Y1.2, Y1.4
GPIO0: C20.1, IC1.5 (GPIO0), Q1.3 (C1), R8.2, S2.1
GPIO18: IC1.24 (DAC_2), R7.2, R14.1
GPIO45: IC1.50 (GPIO45), R9.2
unnamed: AE1.2 (PCB_Trace), R4.2, R5.2
unnamed: C5.1, IC1.52 (XTAL_N), Y1.1
unnamed: C6.1, L1.1, R5.1
unnamed: C8.1, IC1.2 (LNA_IN), L1.2
unnamed: C9.2, IC1.53 (XTAL_P), Y1.3
unnamed: C11.1, IC1.3 (VDD3P3_1), IC1.4 (VDD3P3_2), L2.2
unnamed: C44.1, C45.1, J2.A4 (VBUS), J2.A9 (VBUS), J2.B4 (VBUS), J2.B9 (VBUS), S3.1 (A), TP5.1
unnamed: D1.1 (K), R2.1
unnamed: D1.2 (A), IC1.28 (GPIO21)
unnamed: D2.1 (K), R3.1
unnamed: D3.1 (K), R16.1
unnamed: IC5.10 (OE), R17.2
unnamed: J1.3 (In), R4.1
unnamed: J3.1 (VTref), R13.1
unnamed: LED1.1 (DO), LED2.3 (DI)
unnamed: LED2.1 (DO), LED3.3 (DI)
unnamed: LED3.1 (DO), LED4.3 (DI)
unnamed: LED4.1 (DO), LED5.3 (DI)
unnamed: LED5.1 (DO), LED6.3 (DI)
unnamed: LED6.1 (DO), LED7.3 (DI)
unnamed: LED7.1 (DO), LED8.3 (DI)
unnamed: LED8.1 (DO), LED9.3 (DI)
unnamed: LED10.1 (DO), LED11.3 (DI)
unnamed: LED9.1 (DO), LED10.3 (DI)
unnamed: LED11.1 (DO), LED12.3 (DI)
unnamed: LED12.1 (DO), LED13.3 (DI)
unnamed: LED13.1 (DO), LED14.3 (DI)
unnamed: LED14.1 (DO), LED15.3 (DI)
unnamed: LED15.1 (DO), LED16.3 (DI)
unnamed: LED16.1 (DO), LED17.3 (DI)
unnamed: LED17.1 (DO), LED18.3 (DI)
unnamed: LED18.1 (DO), LED19.3 (DI)
unnamed: LED19.1 (DO), LED20.3 (DI)
unnamed: LED20.1 (DO), LED21.3 (DI)
unnamed: LED21.1 (DO), LED22.3 (DI)
unnamed: LED23.1 (DO), LED28.3 (DI)
unnamed: LED24.1 (DO), LED29.3 (DI)
unnamed: LED24.3 (DI), LED41.1 (DO)
unnamed: LED25.1 (DO), LED30.3 (DI)
unnamed: LED25.3 (DI), LED42.1 (DO)
unnamed: LED26.1 (DO), LED31.3 (DI)
unnamed: LED26.3 (DI), LED43.1 (DO)
unnamed: LED27.1 (DO), LED32.3 (DI)
unnamed: LED27.3 (DI), LED44.1 (DO)
unnamed: LED28.1 (DO), LED33.3 (DI)
unnamed: LED29.1 (DO), LED34.3 (DI)
unnamed: LED30.1 (DO), LED35.3 (DI)
unnamed: LED31.1 (DO), LED36.3 (DI)
unnamed: LED33.1 (DO), LED37.3 (DI)
unnamed: LED34.1 (DO), LED38.3 (DI)
unnamed: LED35.1 (DO), LED39.3 (DI)
unnamed: LED36.1 (DO), LED40.3 (DI)
unnamed: LED37.1 (DO), LED41.3 (DI)
unnamed: LED38.1 (DO), LED42.3 (DI)
unnamed: LED39.1 (DO), LED43.3 (DI)
unnamed: LED40.1 (DO), LED44.3 (DI)
unnamed: LED45.1 (DO), LED50.3 (DI)
unnamed: LED46.1 (DO), LED51.3 (DI)
unnamed: LED46.3 (DI), LED63.1 (DO)
unnamed: LED47.1 (DO), LED52.3 (DI)
unnamed: LED47.3 (DI), LED64.1 (DO)
unnamed: LED48.1 (DO), LED53.3 (DI)
unnamed: LED48.3 (DI), LED65.1 (DO)
unnamed: LED49.1 (DO), LED54.3 (DI)
unnamed: LED49.3 (DI), LED66.1 (DO)
unnamed: LED50.1 (DO), LED55.3 (DI)
unnamed: LED51.1 (DO), LED56.3 (DI)
unnamed: LED52.1 (DO), LED57.3 (DI)
unnamed: LED53.1 (DO), LED58.3 (DI)
unnamed: LED55.1 (DO), LED59.3 (DI)
unnamed: LED56.1 (DO), LED60.3 (DI)
unnamed: LED57.1 (DO), LED61.3 (DI)
unnamed: LED58.1 (DO), LED62.3 (DI)
unnamed: LED59.1 (DO), LED63.3 (DI)
unnamed: LED60.1 (DO), LED64.3 (DI)
unnamed: LED61.1 (DO), LED65.3 (DI)
unnamed: LED62.1 (DO), LED66.3 (DI)
unnamed: LED67.1 (DO), LED72.3 (DI)
unnamed: LED68.1 (DO), LED73.3 (DI)
unnamed: LED68.3 (DI), LED85.1 (DO)
unnamed: LED69.1 (DO), LED74.3 (DI)
unnamed: LED69.3 (DI), LED86.1 (DO)
unnamed: LED70.1 (DO), LED75.3 (DI)
unnamed: LED70.3 (DI), LED87.1 (DO)
unnamed: LED71.1 (DO), LED76.3 (DI)
unnamed: LED71.3 (DI), LED88.1 (DO)
unnamed: LED72.1 (DO), LED77.3 (DI)
unnamed: LED73.1 (DO), LED78.3 (DI)
unnamed: LED74.1 (DO), LED79.3 (DI)
unnamed: LED75.1 (DO), LED80.3 (DI)
unnamed: LED77.1 (DO), LED81.3 (DI)
unnamed: LED78.1 (DO), LED82.3 (DI)
unnamed: LED79.1 (DO), LED83.3 (DI)
unnamed: LED80.1 (DO), LED84.3 (DI)
unnamed: LED81.1 (DO), LED85.3 (DI)
unnamed: LED82.1 (DO), LED86.3 (DI)
unnamed: LED83.1 (DO), LED87.3 (DI)
unnamed: LED84.1 (DO), LED88.3 (DI)
unnamed: LED89.1 (DO), LED90.3 (DI)
unnamed: LED90.1 (DO), LED91.3 (DI)
unnamed: LED91.1 (DO), LED92.3 (DI)
unnamed: LED93.3 (DI), R14.2
unnamed: R1.1, U1.7 (~RST)
RTS: Q1.1 (E2), Q1.5 (B1), U1.14 (~RTS)
SPICLK: IC1.34 (SPICLK), IC3.6 (CLK)
SPICS0: IC1.33 (SPICS0), IC3.1 (~CS)
SPID: IC1.36 (SPID), IC3.5 (DI(IO0))
SPIHD: IC1.31 (SPIHD), IC3.7 (IO3)
SPIQ: IC1.35 (SPIQ), IC3.2 (DO(IO1))
SPIWP: IC1.32 (SPIWP), IC3.3 (IO2)
VDD_SPI: C18.1, IC1.30 (VDD_SPI), IC3.8 (VCC)

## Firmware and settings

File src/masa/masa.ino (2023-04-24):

#include "credentials.h"
#include "Clock.h"
#include "Led.h"
#include "Masa_SHT20.h"
#include "OTA.h"
#include <Preferences.h>
#include <WiFiManager.h> // https://github.com/tzapu/WiFiManager
#include <WiFi.h>
#include <nvs_flash.h>

#define     LEDS_COUNT  22
#define     LEDS_PIN_1  8
#define     LEDS_PIN_2  7
#define     LEDS_PIN_3  5
#define     LEDS_PIN_4  4

#define SDA       10
#define SCL       11
#define LIGHT_SIG 12

#define WIFI_PIN  0

Clock clk;
Led led_1;
Led led_2;
Led led_3;
Led led_4;
Masa_SHT20 sht20(&Wire, SHT20_I2C_ADDR);
WiFiManager wm;
WiFiManagerParameter custom_param_timezone("tz", "Timezone", "", 40);
WiFiManagerParameter custom_param_weather("wt", "Location", "", 40);

String timezone;
String weather;
Preferences preferences;

void setup()
{
  Serial.begin(115200);
  preferences.begin("credentials", false); 
  wm.addParameter(&custom_param_timezone);
  wm.addParameter(&custom_param_weather);
  wm.setSaveParamsCallback(saveParamsCallback);
  delay(1000);
  // Configure and start the WiFi station
  WiFi.mode(WIFI_STA);
//  Reset the WM settings to relaunch web portal.
  if (digitalRead(WIFI_PIN) == LOW)
  {
//    nvs_flash_erase(); // erase the NVS partition and...
//    nvs_flash_init(); // initialize the NVS partition.
    wm.resetSettings();
  }
  bool res;
  res = wm.autoConnect("Masa_AP", "elektroThing"); // password protected app
  if (!res) {
    Serial.println("Failed to connect");
    wm.setConfigPortalTimeout(60);
    ESP.restart();
  }
  setupOTAWiFiMuted("Masa");

  waitForSync();
  Serial.println("Synced!");

  timezone = preferences.getString("timezone", "");
  weather = preferences.getString("weather", "");

  Serial.println(timezone);
  Serial.println(weather);

  clk.init(timezone.c_str(), 60);
  
  led_1.init(LEDS_PIN_1 , LEDS_COUNT);
  led_2.init(LEDS_PIN_2 , LEDS_COUNT);
  led_3.init(LEDS_PIN_3 , LEDS_COUNT);
  led_4.init(LEDS_PIN_4 , LEDS_COUNT);

  led_1.test();
  led_2.test();
  led_3.test();
  led_4.test();

  sht20.initSHT20();
  sht20.checkSHT20();

}
void loop()
{

  ArduinoOTA.handle();
  //  SHT20
  float humd = sht20.readHumidity(); //Read the measured data of air humidity
  float temp = sht20.readTemperature(); //Read the measured temp data


  // Serial.println(temp);

  clk.update();

  int brightness = map(analogRead(LIGHT_SIG), 0, 8000, 2, 100);

  led_1.setBrightness(brightness);
  led_2.setBrightness(brightness);
  led_3.setBrightness(brightness);
  led_4.setBrightness(brightness);

  led_1.setLed(clk.getDigit(3), true);
  led_2.setLed(clk.getDigit(2), true);
  led_3.setLed(clk.getDigit(1), true);
  led_4.setLed(clk.getDigit(0), true);

  led_1.update();
  led_2.update();
  led_3.update();
  led_4.update();

  TelnetStream.print("Time: " + clk.getTime());
  TelnetStream.print(", Temp.: "); TelnetStream.print(temp); 
  TelnetStream.print(", Humd.: "); TelnetStream.println(humd); 
  delay(10);
}

void saveParamsCallback () {
  String tz = custom_param_timezone.getValue();
  String wt = custom_param_weather.getValue();


  Serial.print("Timezone: "); Serial.println(tz);
  Serial.print("Weather: "); Serial.println(wt);

  preferences.putString("timezone", tz); 
  preferences.putString("weather", wt); 

}

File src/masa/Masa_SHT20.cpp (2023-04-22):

/*!
 * @file  Masa_SHT20.cpp
 * @brief  Define the basic structure of class Masa_SHT20
 * @details  Drive SHT20 through this library to get temp and humidity
 * @copyright  Copyright (c) 2010 DFRobot Co.Ltd (http://www.dfrobot.com)
 * @license  The MIT License (MIT)
 * @author  [Zhangjiawei](jiawei.zhang@dfrobot.com)
 * @maintainer  [qsjhyy](yihuan.huang@dfrobot.com)
 * @version  V1.0
 * @date  2021-12-03
 * @url  https://github.com/DFRobot/Masa_SHT20
 */
#include "Masa_SHT20.h"

Masa_SHT20::Masa_SHT20(TwoWire *pWire, uint8_t sht20Addr)
{
  _addr = sht20Addr;
  _pWire = pWire;
}

void Masa_SHT20::initSHT20()
{
    _pWire->begin(10,11);
}

float Masa_SHT20::readHumidity(void)
{
    uint16_t rawHumidity = readValue(TRIGGER_HUMD_MEASURE_NOHOLD);
    if(rawHumidity == ERROR_I2C_TIMEOUT || rawHumidity == ERROR_BAD_CRC){
        return(rawHumidity);
    }
    float tempRH = rawHumidity * (125.0 / 65536.0);
    float rh = tempRH - 6.0;
    return (rh);
}

float Masa_SHT20::readTemperature(void)
{
    uint16_t rawTemperature = readValue(TRIGGER_TEMP_MEASURE_NOHOLD);
    if(rawTemperature == ERROR_I2C_TIMEOUT || rawTemperature == ERROR_BAD_CRC){
        return(rawTemperature);
    }
    float tempTemperature = rawTemperature * (175.72 / 65536.0);
    float realTemperature = tempTemperature - 46.85;
    return (realTemperature);
}

void Masa_SHT20::checkSHT20(void)
{
    byte reg = readUserRegister();
    showReslut("End of battery: ", reg & USER_REGISTER_END_OF_BATTERY);
    showReslut("Heater enabled: ", reg & USER_REGISTER_HEATER_ENABLED);
    showReslut("Disable OTP reload: ", reg & USER_REGISTER_DISABLE_OTP_RELOAD);
}

void Masa_SHT20::setResolution(byte resolution)
{
    byte userRegister = readUserRegister();
    userRegister &= B01111110;
    resolution &= B10000001;
    userRegister |= resolution;
    writeUserRegister(userRegister);
}

byte Masa_SHT20::readUserRegister(void)
{
    byte userRegister;
    _pWire->beginTransmission(_addr);
    _pWire->write(READ_USER_REG);
    _pWire->endTransmission();
    _pWire->requestFrom(_addr, (uint8_t)1);
    userRegister = _pWire->read();
    return (userRegister);
}

void Masa_SHT20::writeUserRegister(byte val)
{
    _pWire->beginTransmission(_addr);
    _pWire->write(WRITE_USER_REG);
    _pWire->write(val);
    _pWire->endTransmission();
}

void Masa_SHT20::showReslut(const char *prefix, int val)
{
    Serial.print(prefix);
    if(val){
        Serial.println("yes");
    }else{
        Serial.println("no");
    }
}

byte Masa_SHT20::checkCRC(uint16_t message_from_sensor, uint8_t check_value_from_sensor)
{
    uint32_t remainder = (uint32_t)message_from_sensor << 8;
    remainder |= check_value_from_sensor;
    uint32_t divsor = (uint32_t)SHIFTED_DIVISOR;
    for(int i = 0 ; i < 16 ; i++){
        if(remainder & (uint32_t)1 << (23 - i)){
            remainder ^= divsor;
        }
        divsor >>= 1;
    }
    return (byte)remainder;
}

uint16_t Masa_SHT20::readValue(byte cmd)
{
    _pWire->beginTransmission(_addr);
    _pWire->write(cmd);
    if(0 != _pWire->endTransmission()){   // Used Wire.endTransmission() to end a slave transmission started by beginTransmission() and arranged by write().
      return (ERROR_I2C_TIMEOUT);
    }
    byte toRead;
    byte counter;
    for(counter = 0, toRead = 0 ; counter < MAX_COUNTER && toRead != 3; counter++){
        delay(DELAY_INTERVAL);
        toRead = _pWire->requestFrom(_addr, (uint8_t)3);
    }
    if(counter == MAX_COUNTER){
        return (ERROR_I2C_TIMEOUT);
    }
    byte msb, lsb, checksum;
    msb = _pWire->read();
    lsb = _pWire->read();
    checksum = _pWire->read();
    uint16_t rawValue = ((uint16_t) msb << 8) | (uint16_t) lsb;
    if(checkCRC(rawValue, checksum) != 0){
        return (ERROR_BAD_CRC);
    }
    return rawValue & 0xFFFC;
}

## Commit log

2023-01-22 created test script
    [USBtoUART.kicad_sch, connectors.kicad_sch, led_array_1.kicad_sch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]
2023-01-23 fixed bug and added increasing brightness into loop
    [test.ino]
2023-04-23 Updated with OTA and WiFiManager
    [masa.kicad_pcb]
2023-04-24 Fixed bug with storing weather location
    [masa.ino]
